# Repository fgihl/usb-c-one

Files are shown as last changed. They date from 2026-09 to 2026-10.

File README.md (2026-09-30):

# HIL USB-C Control

A bench device that sits between a Raspberry Pi and a USB-C device under test (DUT). Host software gets controlled access to the DUT's USB 2.0 data, USB-C CC attachment and 5 V VBUS, so it can emulate unplugging and reconnecting the DUT without touching its cable.

It is intended for controlled hardware-in-the-loop (HIL) lab rigs. It is not a general-purpose USB-C charger, dock or power-distribution product.

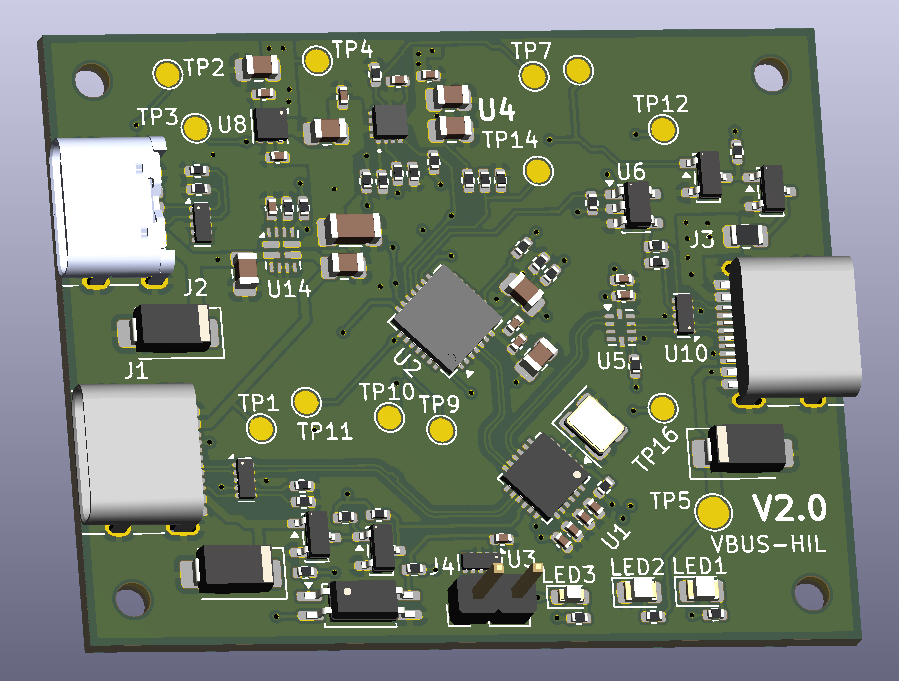
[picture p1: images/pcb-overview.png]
HIL USB-C Control PCB, V2.0 (3D render)


## Features

- USB 2.0 high-speed hub with a fixed on-board control interface. The Pi always sees the controller, whether or not a DUT is connected.
- Software-controlled J3 (DUT) state: data, CC/Rp and 5 V VBUS are switched independently.
- Priority power mux: external 5 V on J2 is preferred; J1 (the Pi) is the fallback and is reverse-blocked when J2 is valid.
- J3 VBUS is protected by an eFuse (about 3.6 A typical, below 4.0 A worst case) with over-voltage protection, fault reporting and active discharge.
- Fixed 3 A Rp advertisement on J3. No USB PD, BC1.2, VCONN, SuperSpeed or alternate modes.
- One opto-buffered external control line (J4) and test points for the key rails and signals.
- Controlled via `libgpiod` on the standard Linux `cp210x` gpiochip.

## Connectors

| Ref | Role |
|---|---|
| J1 | USB-C upstream to the Raspberry Pi: USB 2.0 data, and fallback VBUS |
| J2 | USB-C 5 V power input (power only, no data). Preferred over J1 |
| J3 | USB-C downstream to the DUT: switched data, CC and VBUS |
| J4 | External opto-buffered control line |

## Architecture

```mermaid
flowchart LR
  J1[J1 USB-C to Pi] -->|D+/D-| H[CH334F USB 2.0 hub]
  J1 -->|VBUS_UP| MUX[TPS2121 priority mux]
  J2[J2 5 V input] -->|VBUS_PWR| MUX
  MUX --> VSYS((VSYS))
  VSYS --> LDO[TLV76733 3.3 V LDO]
  LDO --> H
  H -->|port 1, fixed| C[CP2102N GPIO control]
  H -->|port 2| SW[TS3USB221A data switch]
  SW --> J3[J3 USB-C to DUT]
  LDO --> RP[Rp buffer] --> J3
  VSYS --> EF[TPS259470L eFuse] -->|VBUS_HIL| J3
  C --> EF
  C --> SW
  C --> RP
```

| Function | Part |
|---|---|
| USB 2.0 hub | CH334F |
| Control IC | CP2102N-A02 (7 GPIO) |
| Power mux | TPS2121 |
| J3 eFuse | TPS259470L |
| Data switch | TS3USB221A |
| 3.3 V LDO | TLV76733 |
| Rp buffer | SN74LVC1G125 |
| ESD | TPD4E05U06 |

Board: 4 layers, 50 x 40 mm, top-side SMT, designed for JLCPCB assembly.

## Operating cases

| Case | Power source | Use |
|---|---|---|
| A. Pi-powered | J1 only | Low-current DUTs only. Enumeration, data path and low-power control. |
| B. External 5 V | J2, with the Pi supplying data on J1 | Normal mode for high-current tests. The source must supply the DUT load plus about 0.1 A board consumption (at least 3.5 A for a 3 A DUT). |
| C. Split-cable | External 5 V on J1 VBUS, Pi supplies data and GND | Qualified fixtures only. The Pi-side VBUS must be isolated from the external supply. |

J1 and J2 accept regulated 5 V only. Sustained 12 V or 20 V input is outside the product contract.

## Software contract

Software owns the state machine. The hardware does not detect DUT attach and does not enforce source capability.

- **Disconnect:** data off, wait 20 ms, CC off, wait 20 ms, VBUS off, then wait for the discharge confirmation.
- **Connect:** CC on, VBUS on, confirm VBUS present and no fault, wait 40 ms, data on.

Before a high-current test, confirm that J2 is powering the board. Turn J3 VBUS off before planned J2 removal. The CP2102N GPIO map, configuration image and a control-service example are in [architecture/architecture_final.md](architecture/architecture_final.md) section 6.

## Repository layout

| Path | Contents |
|---|---|
| [product_description.md](product_description.md) | Product requirements, operating cases, accepted limitations, acceptance checks |
| [architecture/architecture_final.md](architecture/architecture_final.md) | Schematic-level architecture, power budget, GPIO map, BOM, risks, prototype tests |
| [architecture/schematic_overview.md](architecture/schematic_overview.md) | Schematic overview |
| [architecture/pcb_floor_plan.md](architecture/pcb_floor_plan.md) | PCB floor plan and layout constraints |
| [llm-kicad/](llm-kicad/) | KiCad 10 project (hierarchical schematic, PCB, custom symbols) |
| [llm-kicad/schematic_review_report.md](llm-kicad/schematic_review_report.md) | Schematic review report and finding log |
| [tools/](tools/) | Audit and helper scripts |

The schematic sheets are `01_power_cc`, `02_usb_hub_control`, `03_dut_interface` and `04_test_validation`. Open `llm-kicad/llm-kicad.kicad_pro` in KiCad 10.

## Tools

`tools/audit_schematic.py` checks symbol pin numbers against placed footprint pad numbers, schematic versus PCB footprint sync, `Value` text versus the JLCPCB catalogue part, and `Datasheet` coverage. It exits non-zero if the pin/pad or footprint-sync checks fail.

```sh
python3 tools/audit_schematic.py
```

## Known limitations

- Fixed 3 A Rp: the advertisement can exceed the active source's real capacity.
- No hardware DUT-attach detection: an unplugged DUT can leave J3 VBUS live until software disables it.
- A single priority mux is the only isolation between J1 and J2. It is not an independent-source isolator, and a split cable that joins an external supply to the Pi is not protected against.
- No per-input current limit or input over-voltage disconnect.

The full list and the release acceptance checks are in [product_description.md](product_description.md) sections 7 to 9.

## Status

Hardware revision V2.0. Before release, see the open items in the schematic review report and the mandatory prototype tests in [architecture/architecture_final.md](architecture/architecture_final.md) section 10. The CP2102N must be programmed with the configuration image before use.

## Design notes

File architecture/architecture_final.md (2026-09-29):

# HIL USB-C Control - Schematic-Level Architecture (v1)

Status: Draft for review round 1. This is a complete, standalone architecture derived from `product_description.md`; prior designs are archived in `architecture/V1/`.

## 0. Scope and decisions

| Area | Decision |
|---|---|
| USB topology | USB 2.0 High-Speed hub: one permanent control port and one switchable DUT port |
| Control IC | CP2102N-A02-GQFN28, exposed to Linux as a `cp210x` gpiochip |
| Input power | U14 TPS2121RUXR (C485916) J2-preferred dual-input priority mux with reverse-current blocking; J1 is the fallback |
| HIL power | One TPS259470L eFuse on J3 VBUS: 3.89 A current limit, OVP, fault output, controlled ramp and discharge |
| HIL CC | Software-enabled fixed 3 A Rp from 3.3 V: 4.79 kOhm per CC pin |
| Safety policy | Software sequences CC, VBUS and data. There is no hardware DUT-attach detector or source-capability detector. |
| PCB | Four layers, target 60 x 40 mm, no enclosure, top-side SMT with through-hole connector-shell pegs |
| Excluded | USB 3.x, USB PD, BC1.2, SBU, VCONN, DisplayPort and barrel jack |

**Qualified-input boundary:** J1 and J2 accept regulated 5 V only. They are not specified to survive or block a sustained 12 V or 20 V input. A USB-C PD source remains at vSafe5V because the board has no PD communication, but a PD trigger, a non-compliant source, or a 12 V supply is outside the product contract. Input TVS devices handle ESD and short hot-plug transients, not a sustained wrong-voltage supply.

## 1. Requirements traceability

| Requirement / scenario | How v1 satisfies it |
|---|---|
| Pi host, DUT device | J1 is the USB-C upstream connection to the Pi USB-A host port. J3 is a downstream USB-C DFP. |
| USB 2.0 HS only | CH334F hub, TS3USB221A HS switch, 90 Ohm differential routing and 0.5 pF ESD arrays. |
| Control survives DUT disconnect | CP2102N is fixed on hub port 1; only hub port 2 to J3 is switched. |
| Emulated unplug | U5 opens D+/D-, U6 removes Rp, U4 opens/discharges VBUS; software timing is mandatory. |
| Pi-powered low-current test | U14 selects J1 when J2 is absent. Software only permits a known low-current DUT. |
| External 3 A test | U14 selects J2 whenever valid. Fixture requires 5 V, at least 3.5 A, including board load. |
| Split-cable fixture | J1 accepts isolated external VBUS while Pi provides D+/D-/GND. A cable that ties external VBUS to the Pi is prohibited. |
| Never back-feed Pi | U14 reverse-blocks both inputs; J1 carries no HIL load when J2 is present. |
| HIL overload / short | U4 current limit, fast-trip, thermal latch-off and `HIL_FLT_N` report to software. |
| Deterministic default | CP2102N reset latches and pull resistors keep data open, Rp off, U4 EN low and discharge on. |
| Input fault scope | Only qualified 5 V inputs supported; connector TVS covers ESD/transients, not sustained 12/20 V. |

## 2. Topology and control-IC evaluation

| Option | Evaluation | Decision |
|---|---|---|
| USB 2.0 hub with separate control and DUT ports | Control stays enumerated while J3 is removed; true downstream data isolation is possible. | **Selected** |
| USB mux/data switch only | The CP2102N and DUT cannot coexist on one Pi port. | Rejected |
| Hub port power control only | Does not remove CC or guarantee D+/D- isolation. | Rejected |
| MCU plus hub | Enables richer policy and telemetry but adds firmware, update and debug responsibility. | Rejected for v1 |

| Candidate | GPIO and Linux support | Cost / availability posture | Result |
|---|---|---|---|
| Original CP2102 | No general GPIO | Inadequate | Rejected |
| **CP2102N-A02** | Seven GPIO lines through upstream `cp210x` gpiochip; `libgpiod` control | JLC Extended, archived C964632 | **Selected** |
| CH340 / CH9102 | Serial control only; no suitable standard gpiochip path | Low cost but insufficient GPIO | Rejected |
| FT231X / FT232H | GPIO through `ftdi_sio` / MPSSE | Higher cost; valid fallback | Alternative |
| RP2040 / CH32V / STM32 | Full GPIO and logic via CDC serial | Needs maintained firmware | Rejected |

## 3. Block diagram

```mermaid
flowchart LR
  J1[J1 USB-C upstream to Pi] -->|D+/D-| E1[U9 ESD] --> H[U1 CH334F USB 2 HS hub]
  J1 -->|VBUS_UP| MUX[U14 priority mux\nJ2 preferred]
  J2[J2 USB-C 5 V input] -->|VBUS_PWR| MUX
  MUX --> VSYS((VSYS))
  VSYS --> LDO[U8 3.3 V LDO]
  LDO --> H
  H -->|port 1, fixed| C[U2 CP2102N GPIO control]
  H -->|port 2| SW[U5 TS3USB221A]
  SW --> E3[U10 ESD] --> J3[J3 USB-C DUT]
  LDO --> RP[U6 3 A Rp buffer]
  RP --> J3
  VSYS --> EF[U4 HIL eFuse\n3.89 A / OVP]
  EF -->|VBUS_HIL| J3
  EF --> DIS[Q2/Q3 + 470 Ohm discharge]
  C -->|VBUS_EN / DATA_EN_N / CC_EN_N| EF
  C --> SW
  C --> RP
  E2[U11 ESD] --- J2
  TVS[VBUS TVS] --- J1
  TVS --- J2
  TVS --- J3
```

## 4. Power tree and budget

| Rail | Source / path | Design current | Function |
|---|---|---:|---|
| VBUS_UP | J1 | Pi-port-limited | Low-current fallback source |
| VBUS_PWR | J2 | Qualified 5 V / >=3.5 A | Preferred high-current source |
| VSYS | U14 priority mux | 4.2 A | Board and U4 input |
| +3V3 | U8 TLV76733DRVR | 150 mA | Hub, CP2102N, U5/U6, LEDs |
| VBUS_HIL | U4 TPS259470L | 3.89 A nominal | DUT power |

| Consumer | Rail | Typical | Maximum / allowance |
|---|---:|---:|---:|
| CH334F | +3V3 | 42 mA | 85 mA |
| CP2102N | +3V3 | 9.5 mA | 14 mA |
| U5/U6 and logic | +3V3 | 1 mA | 3 mA |
| LEDs | mixed | 5 mA | 7 mA |
| Regulators / mux Iq | VSYS | 2 mA | 5 mA |
| Board total | VSYS | about 60 mA | 115 mA |

A full 3 A DUT requires at least 3.115 A before connector/cable headroom. The specified J2 fixture source is 5 V and at least 3.5 A. A nominal 3 A charger is not a full-3-A DUT source.

## 5. Schematic implementation

### 5.1 Connectors, power mux and 3.3 V rail

- **J1/J3:** TYPE-C-31-M-12, 16-pin USB 2.0 receptacle with four through-hole shell pegs, LCSC C165948 (archived-verified; recheck stock before order). Join A6/B6 as D+ and A7/B7 as D-. SBU1/SBU2 are explicitly NC with no routed stub and no ESD device because no alternate mode is supported; this is an accepted bench-only ESD limitation.
- **J2:** TYPE-C-31-M-17, six-pin power-only USB-C receptacle, LCSC C283540 (archived-verified; recheck stock). It has VBUS, GND and CC only; no D+/D- path exists to invoke proprietary charging protocols.
- **U14:** TPS2121RUXR (Texas Instruments), LCSC C485916, VQFN-HR-12 2 x 2.5 mm, Extended, $1.044 and 37,201 stock in the Konnect JLC cache. Connect J1 to IN1 (pin 7) and J2 to IN2 (pin 2). Strap PR1 (pin 6) to GND and CP2 (pin 3) to J2 VBUS; CP2 above its 1.06 V reference and PR1 below it explicitly select IN2 whenever J2 is valid. With J2 absent or invalid, IN1 supplies the output. Tie OV1/OV2 (pins 5/4) to GND because inputs are qualified 5 V; connect ST (pin 9) to a 10 kOhm pull-up to +3V3 for source-status observation. Note there is no spare control line for it: all seven CP2102N GPIO are allocated (§6.1) and the QFN28 package has no GPIO.7, so ST is observable only by probing the R33 pad. Set ILIM (pin 10) and SS (pin 11) per the TI equations. The 56 mOhm integrated path and reverse-current blocking prevent J1 from sharing the J2 HIL load. Do not substitute a plain ideal-diode OR circuit.
- U14 is the only isolation element between J1 and J2. Its specified reverse blocking is verified by prototype test, but component failure is not guaranteed open-circuit. This attended, qualified-fixture board is not an independent-source isolator. Label J1/J2 accordingly and test J2 back-voltage with J1 active and vice versa.
- **U8:** TLV76733DRVR, LCSC C2848334 (archived-verified; recheck stock). IN=VSYS, EN=IN, OUT=+3V3, FB/SNS=OUT. C16 1 uF at IN; C17 10 uF/25 V and C18 100 nF at OUT.
- Add 100 kOhm / 100 kOhm dividers from VBUS_UP to GPIO.5 and from VBUS_PWR to GPIO.3. Each provides 2.5 V at a valid 5 V input. They are informational and do not control U14.

### 5.2 HIL VBUS and discharge

- **U4:** TPS259470LRPWR, LCSC C3662793 (archived-verified; recheck stock). IN=VSYS, OUT=VBUS_HIL. C9 10 uF + C10 100 nF at IN. For output transient performance fit C11/C12 as two 10 uF/0805/25 V X5R capacitors in parallel plus C13 100 nF; total nominal bulk is 20 uF. Validate <100 mV sag for a 0-to-3 A load step.
- EN/UVLO is `EN_HIL`: CP2102N GPIO.6 (pin 20, configured push-pull) -> R27 1 kOhm -> EN; R28 10 kOhm EN-to-GND. This yields a deterministic disabled state before GPIO configuration. R28 doubles as the 10 kOhm pull-down the CP2102N datasheet requires, because all pins float high during a device reset.
- ILM: R31=931 Ohm, 0402, 0.1%, LCSC C852955. The TPS259470L data sheet specifies 3.96/4.452/4.84 A min/typ/max at RILM=750 Ohm. Scaling that specified band by $750/(931 \times 1.001)$ and $750/(931 \times 0.999)$ gives 3.19-3.90 A; nominal is 3.59 A. This retains a 3 A DUT margin while bounding maximum current below 4.0 A. Validate the trip response and thermal behavior on prototype, but no further current-limit tolerance derivation is pending.
- OVLO: R29 49.9 kOhm (VSYS to OVLO) and R30 12 kOhm (OVLO to GND), yielding 6.19 V rising / 5.67 V falling. SMAJ6.5A has 6.5 V standoff, not a 6.5 V clamp; it does not suppress a 6.19 V OVLO trip. DVDT C14=1 nF. ITIMER open. FLT has R34 10 kOhm pull-up to +3V3 and reaches GPIO.0. U4 is the **latch-off (-L)** variant, so a thermal or ILM-short fault stays latched until explicitly cleared — the recovery contract is in §6.5. There is deliberately **no supply-side UVLO divider** on EN/UVLO (accepted risk, §10).
- Discharge: Q2 and Q3 are BSS138P,215 (C75547, SOT-23, Extended; 463,528 stock in the Konnect cache). R36 470 Ohm/0805 is from VBUS_HIL to Q3 drain; Q3 source is GND. Q3 gate has R37 100 kOhm pull-up to +3V3. When EN_HIL is high, Q2 conducts and pulls Q3 gate low, turning Q3 off so discharge is disabled. When EN_HIL is low, Q2 releases the gate and R37 turns Q3 on, enabling discharge. Q3 on resistance is negligible compared with 470 Ohm; the nominal 20 uF output discharges from 5 V to 0.8 V in 17 ms. `hil_off()` must report a discharge fault if its 150 ms confirmation timeout expires.
- `VBUS_HIL_SNS`: R38 10 kOhm from VBUS_HIL, R39 18 kOhm to GND, and R40 1 kOhm series to GPIO.1 (pin 18). At 5 V, GPIO sees 3.21 V.

### 5.3 USB hub, control and switched data

- **U1:** CH334F, LCSC C5187527 (archived-verified; recheck stock). Operate in 3.3 V self-powered mode: V5 and VDD33 to +3V3, each with 1 uF + 100 nF. Strap PSELF for the confirmed self-powered polarity. Y1 is X322512MSB4SI 12 MHz, LCSC C9002; external 22 pF load capacitors are DNP because CH334F provides internal loading.
- Hold U1 RESET#/CDP low while J1 VBUS is absent using Q6/Q7, both BSS138P,215/C75547. Q6 source=GND, drain=U1 RESET#, gate=`HUB_RESET_CTL`; R45=100 kOhm pulls RESET# to +3V3. Q7 source=GND, gate=VBUS_UP, drain=`HUB_RESET_CTL`; R46=100 kOhm pulls `HUB_RESET_CTL` to +3V3. With VBUS_UP absent, Q7 is off, Q6 gate is high, and Q6 asserts reset; with VBUS_UP present, Q7 pulls Q6 gate low and R45 releases reset. Never actively drive RESET# high. Confirm PSELF and reset behavior on prototype.
- **U2:** CP2102N-A02-GQFN28R, LCSC C964632 (archived-verified; recheck stock). U2 D+/D- connect to fixed U1 port 1. VDD gets 1 uF + 100 nF; VREGIN gets 1 uF. VBUS sense pin uses R43=22 kOhm from VSYS and R44=47 kOhm to GND.
- **U5:** TS3USB221ARSER, LCSC C128396 (archived-verified; recheck stock). Hub port 2 connects to common D+/D-; J3 connects to 1D+/1D-. Select=GND; 2D+/2D-=NC; OE#=`HIL_DATA_EN_N`; VCC=+3V3 with 100 nF.

### 5.4 CC, Rp, inputs and controls

- J1/J2 each have Rd: R1-R4, 5.1 kOhm from each CC pin to GND. This establishes a Type-C sink and makes a compliant J2 source apply vSafe5V.
- **U6:** SN74LVC1G125DBVR, LCSC C23654 (archived-verified; recheck stock). VCC=+3V3 with 100 nF; A=+3V3; OE#=`HIL_CC_EN_N`; Y=`VRP_3A`. It must offer power-off output isolation.
- From `VRP_3A` to J3 CC1 fit R5=4.7 kOhm; to J3 CC2 fit R6=4.7 kOhm (LCSC C25900, 0402, Basic). A single 4.7 kOhm from a buffered 3.3 V is the USB Type-C Table 4-24 3.3 V-column value for a 3 A advertisement. There is no R7/R8 placement option: the earlier 33 kOhm || 5.6 kOhm split was never built. Specify 1% parts and record the tolerance in the BOM (the specification's 3.3 V Rp leg is 4.7 kOhm +/-5%). Do not fit auxiliary 1 Mohm CC pull-ups: U6 output isolation leaves the line genuinely open when disabled.
- There is no PD controller, BC1.2 detector, VCONN or dynamic Rp. J3 advertises 3 A even in Pi fallback mode; software must prevent inappropriate loads.

## 6. Control interface and Linux contract

### 6.1 GPIO assignment (as built, and routing-verified)

All seven CP2102N GPIO pins on the QFN28 package are **bidirectional** — Rev 1.5
pin table: "Digital Input/Output. General Purpose I/O" for GPIO.0-GPIO.6 — and
every one supports both output modes, §4.3.3: *"Each pin has two options for the
output mode: push-pull and open-drain."* **There is therefore no input/output
constraint on which signal goes on which pin.** Only the per-pin *mode* in the
configuration image has to follow the signal, not the pin number.

The assignment below is what the schematic and board implement. It was also
tested as a routing question: scored against the placed board, it gives **zero
crossings** in the U2 fan-out (the minimum achievable) and a total first-hop
length within 1% (0.64 mm of 52 mm) of the best of all 5040 permutations. The
previous revision of this table was wrong on six of seven pins, and its
arrangement measured 2.75 mm longer **with two crossings** — so the table was
corrected to the hardware, not the hardware to the table.

| GPIO | Pin | Net | Mode | I/O | Active state | Default |
|---|---:|---|---|---|---|---|
| GPIO.0 | 19 | `HIL_FLT_N` | digital input | in | low = U4 fault | pull-up |
| GPIO.1 | 18 | `VBUS_HIL_SNS` | digital input | in | high = HIL VBUS present | divider |
| GPIO.2 | 17 | `HIL_CC_EN_N` | output, open-drain | out | low enables U6 Rp | released / high |
| GPIO.3 | 16 | `U14_ST` | digital input | in | **low = `VBUS_PWR` selected** | R33 10 kOhm pull-up |
| GPIO.4 | 22 | `HIL_DATA_EN_N` | output, open-drain | out | low enables U5 | released / high |
| GPIO.5 | 21 | `EXT_IO0` | output, open-drain, high drive | out | **low = opto LED on** | released / high |
| GPIO.6 | 20 | `HIL_VBUS_EN` | output, **push-pull** | out | high enables U4 | low |

Three points that the mode column depends on:

- `HIL_VBUS_EN` **must be push-pull.** It drives `EN_HIL` through R27 = 1 kOhm
  with R28 = 10 kOhm to GND, so it has to actively source current to exceed the
  TPS259470L's 1.20 V UVLO threshold. As an open-drain output it could not drive
  high and U4 would never enable.
- `HIL_DATA_EN_N` and `HIL_CC_EN_N` are open-drain and rely on R48 = 100 kOhm
  (U5 OE#) and R49 = 100 kOhm (U6 OE#) respectively, so their released state is
  high = disabled. Push-pull would also work; open-drain is used so the reset
  default is already the safe state.
- GPIO.5 **must be open-drain with latch = 1**, so it is inert at reset and through USB
  suspend. The opto LED is wired anode-to-`+3.3V` through R76 = 330 Ohm, cathode to the pin,
  so the pin sinks about 5.6 mA to turn the line on. That is why **high drive** is required:
  low drive sinks only 6.5 mA, which is right at the LED current; high drive sinks 13.5 mA.
  Push-pull would work electrically but its reset state is indistinguishable from asserted if
  the latch is ever set to 0.
- All **two** remaining sense pins (`HIL_FLT_N`, `VBUS_HIL_SNS`) are plain inputs into
  3.3 V-tolerant networks. GPIO.0-GPIO.3 have alternate functions (TXT / RXT / RS485 /
  WAKEUP on QFN28) - all unused and to be left disabled. GPIO.4-GPIO.6 have none.

`VBUS_HIL_SNS` is in §5.2, and `HIL_FLT_N` comes from U4's FLT pin.

**Changed 2026-09-29 - both VBUS sense dividers were removed.** `VBUS_PWR_SNS`
(R70/R71/R72) and `VBUS_UP_SNS` (R73/R74/R75) are deleted from the schematic, and their
test points TP13/TP15 with them. GPIO.5 is needed as an output for the one external
control line that fits, and GPIO.3 is the only other pin whose sense function could be
spent, so neither source can be read directly any more. §6.6.4 is therefore moot: the
sub-`V_IH` divider defect it describes no longer exists in the design, because the
dividers do not exist.

**`U14_ST` replaces them.** U14 is a TPS2121, and its `ST` pin is an open-drain status
output - TPS2121 datasheet, Recommended Operating Conditions: `V_ST` 0-5.5 V and
**`R_ST` "Status Pin Pull Up Resistance" = 6-20 kOhm, an *external* pull-up** (it sits
next to `R_ILM` 18-100 kOhm, which is also external). R33 = 10 kOhm to `+3.3V` is inside
that range, and because the part has no internal pull-up the high level is exactly 3.3 V -
comfortably above the CP2102N's `V_IH` = 2.7 V, and never above 3.3 V.

Datasheet behaviour: *"ST is pulled high when the output is Hi-Z or IN1. It is pulled low
when IN2 is powering the output."* On this board U14 pin 7 (`IN1`) is `VBUS_UP` and pin 2
(`IN2`) is `VBUS_PWR`, so:

| `U14_ST` (GPIO.3) | Meaning |
|---|---|
| high (1) | `VBUS_UP` (upstream USB-C) is powering VSYS, **or** the output is Hi-Z |
| low (0) | `VBUS_PWR` (auxiliary supply) is powering VSYS |

The Hi-Z case is unobservable in practice - both inputs invalid means the fixture is
unpowered. **The polarity is inverted relative to the old `VBUS_PWR_SNS`**, which read
high = present; firmware must flip the bit. The accepted loss is that only the *selected*
source is visible, so "both inputs present at once" can no longer be asserted - that was
the condition that would have verified U14's priority switchover.

### 6.2 Control truth table

| VBUS_EN | CC_EN_N | DATA_EN_N | J3 state |
|---:|---:|---:|---|
| 0 | 1 | 1 | Disconnected: VBUS discharged, Rp absent, D+/D- open |
| 0 | 0 | 1 | Rp present, VBUS/data off |
| 1 | 0 | 1 | VBUS and Rp present; data open |
| 1 | 0 | 0 | Connected: VBUS, Rp and data present |

### 6.3 Configuration image (`cp2102n_config.hex`)

Generate the image from the table in 6.1 — and ultimately from the **netlist**,
never from this document's prose, because a prose-to-netlist drift on exactly
this table is what the pin-permutation defect was. In Xpress Configurator:

| Setting | Value |
|---|---|
| GPIO.0, GPIO.1 | digital input |
| **GPIO.3** | **digital input** (reads U14 `ST`) |
| GPIO.2, GPIO.4 | digital output, **open-drain**, latch = 1 |
| **GPIO.5** | **digital output, open-drain, HIGH DRIVE, latch = 1** |
| GPIO.6 | digital output, **push-pull**, latch = 0 |
| GPIO.0-GPIO.3 alternate functions | disabled (TXT / RXT / RS485 / WAKEUP unused) |
| Suspend behaviour | leave at the default (pin latches hold during USB suspend) |
| Power | self-powered, max power 100 mA |
| UART | RXD (25) and TXD (26) are no-connect, as before |
| Modem pins | `RTS` (24) and `DTR` (28) are output-only test points (TP9/TP16) and need **no** host configuration; `CTS` (23), `DSR` (27), `DCD` (1) and `RI/CLK` (2) stay no-connect |
| Charging pins | CHREN, CHR0/CHR1 unconnected |
| Hardware flow control | **off** |

Release artifact: the generated `.hex`, its SHA-256, and the serial-number
policy. Never allow blank parts into PCBA; program and read back every unit
before final test.

### 6.4 Control service

Use one persistent service to own the GPIO lines. It must request them with the
default-off values already in the table, and must write those values again at
startup before enabling anything.

```python
# CP2102N on a cp210x gpiochip. Line index == GPIO number; confirm with
# `gpioinfo` that the chip labelled cp210x exposes seven lines.
LINE = {"hil_flt_n": 0,   # GPIO.0 pin 19  input
        "vbus_hil_sns": 1, # GPIO.1 pin 18  input
        "cc_en_n": 2,      # GPIO.2 pin 17  open-drain output
        "u14_st": 3,       # GPIO.3 pin 16  input; LOW = VBUS_PWR powering VSYS
        "data_en_n": 4,    # GPIO.4 pin 22  open-drain output
        "ext_io0": 5,      # GPIO.5 pin 21  open-drain output; LOW = opto LED on
        "vbus_en": 6}      # GPIO.6 pin 20  push-pull output

def hil_off():
    """Disconnected state. Returns only once VBUS has actually collapsed."""
    data_en_n.set(1); sleep(0.020)
    cc_en_n.set(1);   sleep(0.020)
    vbus_en.set(0)
    if not wait_until(lambda: not vbus_hil_sns.get(), timeout=0.150):
        raise RuntimeError("VBUS discharge timeout")

def hil_on(high_current=False):
    # high_current means the DUT is to run from the auxiliary supply, so that supply
    # must be the one actually powering VSYS. U14_ST is now the only way to know:
    # it reads LOW exactly when U14 has selected IN2 = VBUS_PWR.
    if high_current and u14_st.get():
        raise RuntimeError("aux supply not selected - is J2 connected and valid?")
    cc_en_n.set(0)
    sleep(0.010)          # let Rp settle before presenting VBUS
    vbus_en.set(1)
    wait_until(lambda: vbus_hil_sns.get() and hil_flt_n.get(), timeout=1.0)
    sleep(0.040)          # inrush/ramp settles before closing the data path
    data_en_n.set(0)

def ext_out(asserted):
    """Drive the single external opto-isolated line.

    Path: GPIO.5 -> U15 LED -> U15 collector -> EXT_OUT0 -> U3 clamp -> J4 pin 2.
    Active low, and the polarity is preserved end to end: asserted sinks the LED,
    which turns the phototransistor on and pulls the far-side node to GND.
    Released (and unpowered) leaves it pulled up by R79, so the DUT-side default
    is the inert high.
    """
    ext_io0.set(0 if asserted else 1)

def source_selected():
    """'vbus_pwr' | 'vbus_up'. Note ST is inverted versus the old sense divider."""
    return "vbus_pwr" if not u14_st.get() else "vbus_up"
```

A fault-recovery path is also required — see §6.5.

### 6.5 Fault latch-off and recovery (U4)

U4 is the **TPS259470L**, the latch-off variant. Per the datasheet (Table 7-3) some
faults latch internally and stay latched until explicitly cleared, while others do
not:

| Event | Response | Latched? | FLT pin |
|---|---|---|---|
| Overtemperature (TJ >= TSD) | Shutdown | **Yes** | low |
| ILM pin shorted to GND | Shutdown | **Yes** | low, after tITIMER |
| Undervoltage (UVP or UVLO) | Shutdown | No | high |
| Input overvoltage | Shutdown | No | high |
| Persistent overcurrent | Current limit | No | low, after tITIMER |
| ILM pin open (steady state) | Shutdown | No | low, after tITIMER |
| Output short to GND | Current limit | No | high |
| Reverse current | Reverse-current blocking | No | low |

Because **ITIMER is open**, a sustained overcurrent is *limited* rather than latched:
the part sits in current limit and only latches if it then overheats. So on this
board the latched faults to design for are **overtemperature** and **ILM shorted to
GND**.

**How a latched fault is cleared** (Table 7-2 and §7.3.9). The die must first fall
below `TSD - TSD_HYS`, and then **either**:

1. VIN cycled to 0 V and back above `VUVP(R)` (~2.53 V), or
2. **the EN/UVLO pin taken below `VSD(F)`** — min 0.45 V, max 0.74 V.

**The trap, in the datasheet's own words:** *"During a latched fault, pulling the
EN/UVLO just below the UVLO threshold has no impact on the device."* The UVLO falling
threshold is `VUVLO(F)` = 1.09 V typ, which is **above** `VSD(F)` (0.74 V max). Taking
EN low to a level that merely crosses the UVLO threshold leaves the part latched, and
so does releasing it to high impedance: at high impedance `EN_HIL` sits at the
R27/R28 divider level, which is above `VSD(F)`. The low must be a **hard low, below
0.74 V with margin** — target below 0.45 V so it holds across the full tolerance band.

This design can meet that: `HIL_VBUS_EN` (GPIO.6, push-pull) drives `EN_HIL` through
R27 = 1 kOhm with R28 = 10 kOhm to GND, so driving the line low pulls `EN_HIL` to
about 0 V.

**Software contract:**

- `hil_off()` already drives `HIL_VBUS_EN` low, so it *is* the recovery primitive. Its
  low period must be explicit — hold low for at least 10 ms — rather than left to
  call ordering.
- Provide `hil_fault_clear()` = the EN-low hold followed by re-enable. After a thermal
  or ILM-short fault, FLT stays low until this is done, so treat "FLT low and
  `VBUS_HIL_SNS` low" as **latched — needs a clear**.
- Do **not** auto-retry in a tight loop while the cause persists. A latched thermal
  fault means the DUT is overloading the fixture or the board is too hot. Report it
  and require an explicit command, or retry with a bounded back-off that is recorded.
- Clearing the latch also **releases FLT**. FLT returning high is not evidence that the
  load is healthy — re-check `VBUS_HIL_SNS` and the actual current before resuming.
- While latched, `VBUS_HIL` is off, so `VBUS_HIL_SNS` reads low. Software must not
  report that as "DUT unplugged" when it is the consequence of its own fault latch.
- The Pi cannot power-cycle `VSYS` (option 1 above) without dropping the whole fixture,
  so the EN toggle is the only practical recovery path — which is exactly why the
  hard-low requirement matters. Confirm it on the prototype (mandatory prototype
  test 5).

### 6.6 Planned change: additional host-controllable I/O (partly built)

**Status 2026-09-29: BUILT, and reduced from three channels to one.** Only one external
line fits the board, so sheet 04 carries a single optocoupler stage (`U15`) driven by GPIO.5,
with its clamp, filter capacitor and 2-pin connector. `DTR` and `RTS` were **not** given opto
stages - they are broken out as test points `TP9`/`TP16` instead. §6.1 is now the as-built
record for the seven GPIOs. What remains is the config image and the PCB work.

**Interface decision (revised from the first draft):** the output stage uses an
**optocoupler**, not a directly-driven open-drain line. For "might be 3.3 V, might be 5 V" the
opto is the better answer: the far-side logic level is set by the far side's own pull-up, so
one board works at any level, and the barrier means a mis-wire on the connector provably
cannot reach the CP2102N. It supersedes the DNP `BSS138` branch — do not fit both.

Motivation: the fixture needs general-purpose lines the host can drive to control external
equipment. The first use case is enabling and cutting power to the DUT from an **external
bench supply**, independently of the on-board U4 eFuse path.

#### 6.6.1 Where the extra lines come from

CP2102N §4.3.1 caps the part at "up to 7 GPIO", so there is no eighth GPIO, and the rail
senses cannot be merged onto one pin because the GPIOs are **digital only — the part has no
ADC**, so a resistor ladder cannot distinguish levels. The extra lines therefore come from
two places: one freed GPIO, and the part's unused modem-control interface.

| Line | Source | Direction | Notes |
|---|---|---|---|
| `EXT_IO0` | GPIO.5 (pin 21), freed | out | was `VBUS_UP_SNS` |
| `EXT_IO1` | `RTS` (pin 24) | out | test point `TP9` only - no opto fitted |
| `EXT_IO2` | `DTR` (pin 28) | out | test point `TP16` only - no opto fitted |
| `U14_ST` | GPIO.3 (pin 16) | in | takes over from `VBUS_PWR_SNS` |

#### 6.6.2 `U14_ST` to GPIO.3, freeing GPIO.5

TPS2121 `ST` is an open-drain status output: **high = IN1 (`VBUS_UP`) is feeding VSYS;**
**low = IN2 (`VBUS_PWR`) is feeding VSYS.** In this design U14 pin 7 = IN1 = `VBUS_UP` and
pin 2 = IN2 = `VBUS_PWR`, and J2 has hard priority through the CP2/PR1 comparison. ST is
also high when the output is Hi-Z, which is unobservable here: with no selected source the
board is unpowered and the host cannot read the pin. One pin therefore carries both
input-presence facts, so it replaces `VBUS_PWR_SNS` **and** `VBUS_UP_SNS`:

- GPIO.3 takes `U14_ST`. The net must become a **global label** — this project has no
  hierarchical labels, and U2 lives on a different sheet from U14.
- GPIO.5 becomes **free**: delete R73/R74/R75 and the `VBUS_UP_SNS` label. TP15 sits on that
  net and goes with it — re-point TP15 at `VBUS_UP` if raw-rail probing is still wanted.
- Delete R70/R71/R72 and the `VBUS_PWR_SNS` label; TP13 goes with it.

**No new components are needed for this.** `R33` is already a 10 kOhm pull-up from `U14_ST`
to `+3.3V`, so ST is already a clean 3.3 V logic signal — **do not add a divider.**

**Polarity inverts.** The old `VBUS_PWR_SNS` read high = present; `U14_ST` reads **low =
`VBUS_PWR` selected**. The firmware bit must be updated with it.

**Accepted loss:** ST reports only the *selected* source, so "both inputs present at once"
is no longer observable. That is precisely what would be checked to verify U14's priority
switchover, so if that test matters, keep `VBUS_PWR_SNS` and put ST on GPIO.5 instead —
which then frees nothing.

#### 6.6.3 `DTR` and `RTS` as extra outputs

These are **modem-control functions, not GPIO** (CP2102N §4.3.11), enabled by the VCP
driver when the host configures the COM port. From Linux via pySerial: `p.dtr = True`,
`p.rts = ...` to drive; `p.cd`, `p.dsr`, `p.ri`, `p.cts` to read. This is a **second device
node**, not the cp210x gpiochip.

Two cautions straight from the datasheet:

- **"DTR ... may toggle when opening a COM port on some operating systems."** For a
  power-control line this is the main practical hazard; choose a polarity where the toggle is
  inert, or filter it (100 kOhm / 100 nF = about 10 ms into a Schmitt input).
- Do not enable RTS/CTS **hardware handshaking** (§4.3.7) if RTS is repurposed.

`DCD` (1), `DSR` (27), `RI` (2) and `CTS` (23) stay no-connect for now. They are the
documented extension path for host-readable inputs.

#### 6.6.4 Defect found while deriving this: two sense dividers are below `V_IH`

CP2102N Table 3.7 gives **`V_IH` = VIO - 0.6 = 2.7 V** (VIO = VDD = 3.3 V; the QFN28 has no
separate VIO pin). Against that:

| Sense | Divider | Level at VBUS = 5.0 V | vs `V_IH` = 2.7 V |
|---|---|---|---|
| `VBUS_PWR_SNS` | R70 100 kOhm / R71 100 kOhm | **2.50 V** | below spec |
| `VBUS_UP_SNS` | R73 100 kOhm / R74 100 kOhm | **2.50 V** | below spec (net being removed anyway) |
| `VBUS_HIL_SNS` | R38 10 kOhm / R39 18 kOhm | 3.21 V | fine |

At the USB minimum of 4.75 V the first two fall to 2.375 V. They work in practice — real
thresholds sit nearer VDD/2 — but they are out of specification and should not be relied on
in a fixture.

**Fix:** change **R71 from 100 kOhm to 150 kOhm** (3.00 V at 5.0 V, 2.85 V at 4.75 V, both
comfortably above 2.7 V). R74 disappears with `VBUS_UP_SNS`. The replacement sense needs no
change: R33 already pulls `U14_ST` to `+3.3V`.

#### 6.6.5 External interface: protection rules

The CP2102N is the only host link on the board — if it is damaged the whole fixture becomes
unreachable — so it must be the best-protected part on the board. Threats on an exposed
line: ESD through the connector, a mis-wire putting an external rail onto a signal, a short
to GND, reverse polarity, ground offset between fixture and external equipment, inductive
kickback, and hot-plug transients.

Rules adopted:

1. **Never take the chip pin to a connector unbuffered.** Series resistor (100 Ohm) plus a
   clamp **at the connector**, not at the chip.
2. **Reuse the existing ESD array.** `TPD4E05U06` (already fitted as U9/U10/U11 — 4 channels,
   5.5 V working voltage, +/-12 kV contact) covers four lines with one part. It clamps
   *transients*; it is not sustained-overvoltage protection.
3. **Open the interface where the part allows it.** Table 3.7 specifies input leakage for
   `VIO < VIN < VIO + 2.0 V`, and §4.3.3 permits an open-drain output to be "pulled to the
   higher, external voltage through an external pull-up resistor". So reaching 5 V needs no
   level shifter. Keep any external pull-up at or below `VIO + 2 V` (5.3 V).
4. **Above about 5 V, or driving real current, needs a barrier.** `BSS138` is already in the
   BOM (Q2/Q3/Q6/Q7); at 60 V Vds / +/-20 V Vgs it survives a 12/24 V mis-wire. Per-line
   barrier footprints are placed but **DNP**, so a line can be converted without a respin.
5. **Define the safe state in all four conditions**: unpowered, during reset, with the port
   closed, and during USB suspend. The GPIO default is open-drain with a weak pull-up and
   latch = 1, i.e. released/high; §4.3.1 makes the suspend and post-reset states
   configurable, so set them explicitly in the config image.
6. **Keep "loss of host = safe".** If the PC crashes or the cable is pulled, DTR normally
   releases — arrange the external logic so the DUT then loses power.
7. **Connector hygiene**: keyed or unambiguously silkscreened, a GND pin adjacent to every
   signal, a DNP series-resistor footprint per line, a test point per line, and the clamp
   return kept short to the In1/B.Cu ground plane. If the lines leave the enclosure on a
   cable, add 100 pF - 1 nF per line to ground and consider a common-mode choke.

#### 6.6.6 Circuit adopted per output line

> **Superseded (2026-09-29).** This variant was not adopted. The operator rejected taking a
> CP2102N pin to a connector at all, and chose an optocoupler buffer instead — see §6.6.9.
> The text below is kept as the record of the alternatives that were considered, including
> the DNP `BSS138` branch, which is no longer needed because the opto already provides the
> barrier.

```
CP2102N pin --[100R]--+-- connector pin --+-- [10k] to GND
                      |                   +-- [100pF] to GND
                      |                   +-- TPD4E05U06 channel
                      +-- [DNP: BSS138 gate + 100k to GND, drain pulled to external rail]
```

Output mode: **push-pull, default low**. `EXT_IO0`/`EXT_IO1`/`EXT_IO2` therefore read
**low = inert** at the connector, which is also the state with the board unpowered (the
10 kOhm pull-down). The DNP `BSS138` branch converts a line to an inverting open-drain drive
whose high level is set by the far side, for a >5 V or active-low load.

New connector **J4**, 1x6 keyed header: `GND, EXT_IO0, EXT_IO1, EXT_IO2, EXT_IN0, EXT_IN1`.
The two `EXT_IN` positions are reserved and unpopulated for now; populating them costs one
divider each and shares the existing ESD array.

Assumptions taken when this was written (the operator was not available to confirm them):
the far side is a **high-impedance logic input**; the external domain is **3.3 V, with up to
24 V mis-wire tolerance via the DNP barrier**; **common ground** is assumed, so no galvanic
isolation is fitted — if the external equipment turns out to be floating or on a separate
earth, an opto or digital isolator stage is required instead, and the DNP footprint is where
it goes.

#### 6.6.7 What the change touches

- `01_power_cc.kicad_sch`: `U14_ST` promoted to a global label; R70/R71/R72 and R73/R74/R75
  removed; `VBUS_UP_SNS` and `VBUS_PWR_SNS` labels removed.
- `02_usb_hub_control.kicad_sch`: U2 pins 21, 28 and 24 un-no-connected; new `EXT_IO*`
  labels; new J4 and its protection network.
- `architecture_final.md`: this section, plus §6.1, §6.2 (source-selection readback) and §9 BOM.
- `cp2102n_config.hex`: regenerate — GPIO.5 push-pull output with its reset and suspend latch
  set to the inert state; GPIO.3 unchanged as a digital input; confirm no handshaking.
- Linux control service: `EXT_IO0` still on the cp210x gpiochip; `EXT_IO1`/`EXT_IO2` and any
  inputs through pySerial on the VCP device node.

#### 6.6.8 Implementation status and the built circuit

**Built on sheet 04 (`04_test_validation.kicad_sch`), right-hand side - ONE channel:**

| Ref | Part | Value | Footprint | LCSC |
|---|---|---|---|---|
| U15 | `Isolator:PC817` symbol, LTV-217 part | `LTV-217` | `Package_SO:SOP-4_4.4x2.6mm_P1.27mm` | C115450 |
| R76 | LED series resistor | `330R 0402` | `R_0402_1005Metric` | C25104 |
| R79 | output pull-up | `10k 0402` | `R_0402_1005Metric` | C25744 |
| U3 | 4-channel ESD clamp array | `TPD4E05U06DQA` | `Package_SON:USON-10_2.5x1.0mm_P0.5mm` | C138714 |
| C2 | connector filter capacitor | `100pF` | `Capacitor_SMD:C_0402_1005Metric` | C1546 |
| J4 | far-side connector | 1x2, 2.54 mm | `PinHeader_1x02_P2.54mm_Vertical` | C49257 |
| TP9, TP16 | `DTR` / `RTS` breakout | `EXT_I01`, `EXT_02` | - | C49257 |

Wiring: `+3.3V` - R76(330R) - U15 pin 1 (anode); U15 pin 2 (cathode) - global label
`EXT_IO0`; U15 pin 3 (emitter) - GND; U15 pin 4 (collector) - global label `EXT_OUT0`,
R79(10k) to `+3.3V`, C2 to GND, and U3 channel D1+ (plus its straight-through NC pin 10,
which TI sanctions) on to J4 pin 2.

`U15` is driven by **GPIO.5 (pin 21)** - `EXT_IO0` reaches `U2.21`. The two unused clamp
channels and the other three `TPD4E05U06` pins are left floating.

**Note:** only one of the array's four channels is used, so the 10-pin USON `U3` is now
larger than the job needs. The same device family has a single-channel part,
**`TPD1E05U06`** (2-pin X1SON 0.6x1 mm or DFN1006-2; C2937017 $0.033, C436349 $0.06,
C3001953 $0.024) - worth swapping if board space gets tight. TI's layout footnote still
applies: keep it at the connector.

- **Drive the LED by sinking, never sourcing.** The CP2102N is asymmetric: 7 mA source but
  **13.5 mA sink** in high-drive mode (3.1.7). +3.3 V through 330 Ohm gives about **5.6 mA**
  of LED current, right at the LTV-217's 5 mA CTR test condition. Configure the driving GPIO
  as **open-drain, high drive** — released/high is then LED off, i.e. the reset and suspend
  defaults are already the inert state.
- **Connector polarity is active-low**: the phototransistor conducts and pulls the far-side
  node low when the LED is on. An active-high far side needs one extra inversion stage.
- **CTR is 130-260 % at 5 mA**, so the 10 kOhm pull-up is comfortable even at half typical
  CTR and after CTR degradation with age and temperature.
- **Cost of the choice:** about 5.6 mA from the 3.3 V rail whenever the line is asserted,
  microsecond edges, and one extra 4-pin part. (Three channels were once planned; only one
  is fitted, so the rail cost is one third of the figure quoted in earlier revisions.)
- The `isolated_pin_label` warnings are **gone**. They cleared once `EXT_IO0` reached
  `U2.21` on sheet 02.

**Trap hit and fixed while placing these:** `add_power_symbol` auto-numbers `#PWR` "to the
lowest number free **on the sheet**", which collided with sheet 02 (it produced `#PWR010`..
`#PWR015`, all already used there). KiCad requires `#PWR` references to be unique across the
whole project; the duplicates made `kicad-cli sch export netlist` print *"schematic has
annotation errors"*. They were renumbered to `#PWR0200`..`#PWR0205`. Always check `#PWR`
uniqueness **project-wide**, not per sheet, after adding power symbols.

**Protection network built (2026-09-29).** Between U15's collector and J4 there is a 10 kOhm
pull-up (R79), a 100 pF capacitor (C2) and one `TPD4E05U06` channel (`U3` D1+, whose
straight-through NC pin 10 TI sanctions carrying the signal on to the connector). Verified
from the netlist:

```
EXT_OUT0 -> C2.1, J4.2, R79.1, U15.4, U3.1, U3.10
EXT_IO0  -> U15.2, U2.21          the LED is now driven by GPIO.5
U14_ST   -> R33.1, U14.9, U2.16   ST on GPIO.3, 10 kOhm pull-up to +3.3V
```

See §6.6.9 for why each of those parts is there.

**Sheet 02 is done.** Pins now read: `U14_ST` on 16 (GPIO.3), `EXT_IO0` on 21 (GPIO.5),
`EXT_IO1` on 24 (`~{RTS}`) and `EXT_IO2` on 28 (`~{DTR}`) - the last two to test points only.
`~{CTS}` (23), `~{DSR}` (27), `~{DCD}` (1) and `~{RI}` (2) keep their no-connect flags, and no
pin carries both a label and a no-connect flag.

**Remaining:**

- **`cp2102n_config.hex`** - the only schematic-adjacent task left. GPIO.5 must become an
  output (open-drain, high drive, latch 1); GPIO.3 stays a digital input; hardware flow
  control off. Generate it from the netlist, never from §6.1's prose.
- **PCB:** `U3` and `C2` must sit **at J4**, not at the opto - TI's pin table says "Place as
  close to the connector as possible" for every clamp channel.
- **PCB:** U15/R76/R79 also want to be near J4 rather than where the schematic draws them.
- **Cosmetic, but it prints on the silkscreen:** J4's Value reads `Conn_01x02_Socket` on a
  header footprint, and the two new test points read `EXT_I01` (should be `EXT_IO1`) and
  `EXT_02` (should be `EXT_IO2`).
- **`J4` has no LCSC code** since the symbol was swapped from 1x3 to 1x2 (the old `C49257`
  was a 1x3 part). A 1x2 2.54 mm replacement: `C492410` (`PZ254R-11-02P`).

**Schematic layout note.** The capacitors were first placed in a vertical chain at x = 238.76
and ran straight through the title block (which occupies x 177-285, y 166-198 on A4
landscape). They were moved into the clear band above it as a horizontal row at y = 146-159.
Check the title block's extent before placing anything in the lower-right of an A4 sheet.

#### 6.6.9 Interface decision (adopted 2026-09-29): opto-buffered open collector

**The CP2102N is never taken to a connector.** Each of the three host-control lines is
buffered by an optocoupler, so the chip pin only ever sees its own LED loop inside a package.
This supersedes both variants in §6.6.6 — the bus-buffered open drain, and the DNP `BSS138`
branch, which is now redundant because the opto already provides the barrier.

**No galvanic isolation is claimed or provided.** U15 pin 3 (emitter) returns to *board* GND
and the 10 kOhm pull-up goes to *board* +3.3 V, so both sides of the barrier reference the
same ground and the isolation rating does nothing. This was a deliberate
acceptance, not an oversight: the DUT is already tied to the fixture ground through USB-C
(J3), so there is no separate far-side ground to isolate to, and real isolation is not
achievable in this topology. The opto earns its place as a **signal** barrier — a transient
on the collector cannot reach the gate-side node at all — not as an isolation barrier.

**Why an ESD clamp is still needed.** Without one, energy at J4 flows into the first thing on
the net: the 10 kOhm 0402 pull-up (rated about 50 V, so it simply breaks down) and then the
+3.3 V rail, which feeds U1 and U2. The opto bounds but does not remove that path, so `U3`
puts one `TPD4E05U06` channel on the line and shunts the pulse to GND. The part is
0.5 pF / 5.5 V working / IEC 61000-4-2 rated and is already in the BOM as U9/U10/U11. It
clamps **transients only**; its 5.5 V standoff means it is the wrong part if a line is ever
left parked at 12 V.

**Why 100 pF.** With the 10 kOhm pull-up it sets a deliberate edge-rate limit:

$$\tau = RC = 10\,\text{k}\Omega \times 100\,\text{pF} = 1\,\mu\text{s} \qquad
f_c = \tfrac{1}{2\pi RC} \approx 159\,\text{kHz}$$

so cable-induced RF, contact bounce on plugging in and ESD remnants are all integrated away
instead of becoming a logic edge; the slower edge also removes the high-frequency harmonics a
cable would otherwise radiate (CISPR/EN 55032), and it gives the clamp diodes an AC path to
GND so they have time to turn on. It is small on purpose: 100 nF against 10 kOhm would give
1 ms, far too slow for a control line.

**Layout rule.** TI's pin table footnote on every clamp channel reads *"Place as close to the
connector as possible"*. `U3` and `C2` must therefore be placed at **J4** in the PCB layout,
with the clamp's ground return kept short to the In1/B.Cu plane — not next to the opto, where
they are drawn on the schematic.

**Accepted limitations.** The 10 kOhm on-board pull-up fixes the idle high level at 3.3 V; a
DUT-side pull-up to its own (e.g. 5 V) rail overrides it and the node settles about 0.5 V
below that rail, which is still a valid high — but a 5 V input with *no* pull-up of its own
would only see 3.3 V, below 5 V CMOS `V_IH` (about 3.5 V). `EXT_IO1`/`EXT_IO2` were reduced to
test points (`TP9`/`TP16`) and carry no opto stage, so if they are driven at all it is as modem
outputs through pySerial rather than from the cp210x gpiochip. `EXT_IO0` is the only line that
uses a real GPIO, and it is now connected to `U2.21` (see §6.6.8).

## 7. Sequences and fail-safe states

```mermaid
sequenceDiagram
  participant Pi
  participant CP as CP2102N
  participant U5 as Data switch
  participant U6 as Rp buffer
  participant U4 as HIL eFuse
  Pi->>CP: data off
  CP->>U5: OE# high, D+/D- open
  Note over Pi: wait 20 ms
  Pi->>CP: CC off
  CP->>U6: OE# high, Rp open
  Note over Pi: wait 20 ms
  Pi->>CP: VBUS off
  CP->>U4: EN low, output off
  U4->>U4: 470 Ohm discharge, below 0.8 V within 36 ms
```

```mermaid
sequenceDiagram
  participant Pi
  participant CP as CP2102N
  participant U6 as Rp buffer
  participant U4 as HIL eFuse
  participant U5 as Data switch
  Pi->>CP: CC on, VBUS on
  CP->>U6: Rp enabled
  CP->>U4: EN high, controlled VBUS ramp
  Pi->>CP: check VBUS_HIL_SNS and FLT_N
  Note over Pi: wait 40 ms
  Pi->>CP: data on
  CP->>U5: OE# low, DUT enumerates
```

```mermaid
sequenceDiagram
  participant DUT
  participant U4 as HIL eFuse
  participant CP as CP2102N
  participant Pi
  DUT->>U4: overload / short
  U4->>U4: current limit then fast-trip or thermal latch
  U4->>CP: FLT_N low
  CP->>Pi: fault event
  Pi->>CP: data off, CC off, VBUS off
```

| Condition | J3 state | Mechanism |
|---|---|---|
| Power-up, U2 reset, failed enumeration | Disconnected | GPIO latches and pull resistors |
| Pi reboot | Disconnected until service starts | Same defaults |
| U4 thermal fault | VBUS off, FLT low | U4 latch-off; service disables all outputs |
| DUT physically unplugged | Can remain powered until service turns it off | Accepted software-only limitation |
| J2 added while J1 present | J2 supplies VSYS, J1 reverse-blocked | U14 priority mux |

## 8. ESD, indicators, test points and layout

| Location | Protection / implementation |
|---|---|
| J1 D+/D-/CC1/CC2 | U9 TPD4E05U06DQAR, C138714, 0.5 pF ESD array |
| J3 D+/D-/CC1/CC2 | U10 TPD4E05U06DQAR, C138714 |
| J2 CC1/CC2 | U11 TPD4E05U06DQAR, C138714; unused channels grounded |
| J1/J2 VBUS | SMAJ20A, C115250. Transient/ESD support only; sustained incorrect voltage is unsupported. |
| J3 VBUS | SMAJ6.5A, C123817, coordinated with U4 OVLO |
| LEDs | Green VSYS, yellow VBUS_HIL, red +3V3-to-FLT_N; 1 kOhm each |
| Test points | VBUS_UP, VBUS_PWR, VSYS, +3V3, VBUS_HIL, GND, U4 ILM/EN/FLT, three GPIO enables, three GPIO senses, D+/D- in-route vias |

- Shells go directly to GND with short, wide copper and at least four stitching vias per connector. Reserve DNP 1 Mohm || 4.7 nF chassis-link footprints only if a metal enclosure is added.
- Use four layers: L1 signals/components, L2 solid GND, L3 VSYS/VBUS_HIL pours, L4 low-speed signals. Route USB at 90 Ohm differential impedance using JLC's chosen four-layer stack-up, <0.15 mm skew, no stubs and <=2 vias per pair.
- Floor plan: J1 left edge; U9 then U1/Y1 left-center; J2 top edge beside U14 and input TVS; U4/bulk capacitors top-right; U5/U10 between U1 and J3 on right edge; U2 bottom-center; U8 near the 3.3 V loads. Keep ESD within 3 mm of connector pins and switching/high-current loops away from Y1/U1.
- Barrel jack is dropped: a safe third source needs reverse blocking and a qualified OVP path, exceeding the three-part target. Use a regulated USB-C supply at J2.
- Thermal target: U14 dissipation at 3.12 A is approximately $3.12^2 \times 56\ m\Omega = 0.55\ W$ nominal. U4 is approximately $3^2 \times 17\ m\Omega = 0.15\ W$ using its typical on resistance. Place U14 and U4 over copper pours with at least four thermal vias. U8 worst-case dissipation is $(5.25-3.3) \times 0.115 = 0.22\ W$. At 3 A DUT load from J2, measure 10-minute temperature rise; no device may thermal-shutdown and U14/U4 package surface rise should remain below 40 C above ambient.
- Before PCB layout, select the current JLC four-layer impedance stack-up in its impedance calculator and record its 90 Ohm differential width/spacing in the PCB constraints. This architecture does not freeze a stack-up code that JLC could change.

## 9. BOM summary and procurement status

| Group | Approx. qty | Cost at qty 10 | Status |
|---|---:|---:|---|
| ICs, connectors, TVS, FETs, LEDs, crystal | 24 | $8-11 | Includes Q2/Q3/Q6/Q7; all core entries were rechecked in the Konnect cache below |
| Resistors | 36 | about $0.35 | 0402 except R36 470 Ohm 0805 |
| Capacitors | 23 | about $0.90 | Includes 20 uF output bulk and VSYS bulk |
| Total | 83 BOM placements (+14 test points, +4 mounting holes) | $10-14 plus assembly fees | 35 unique LCSC codes |

The passive table below is generated **from the design**, grouped by part code, and was reconciled against the schematic on 2026-09-28. The earlier revision listed two parts that do not exist (R7/R8) and carried pre-fix values for R28, R34, R5/R6, C23/C25 and C5 — see the review report's H4/H5/M2/M11 findings.

| Passive / refdes | Value and package | LCSC | Qty |
|---|---|---|---:|
| R1-R4 | 5.1 kOhm, 0402, 1% (J1/J2 Rd) | C25905 | 4 |
| R5/R6 | 4.7 kOhm, 0402, 1% (J3 Rp) | C25900 | 2 |
| R27/R40/R47/R50/R51/R52/R72/R75 | 1 kOhm, 0402, 1% | C11702 | 8 |
| R28/R33/R34/R35/R38 | 10 kOhm, 0402, 1% | C25744 | 5 |
| R37/R45/R46/R48/R49/R70/R71/R73/R74 | 100 kOhm, 0402, 1% | C25741 | 9 |
| R29 | 49.9 kOhm, 0402, 1% | C25897 | 1 |
| R30 | 12 kOhm, 0402, 1% | C25752 | 1 |
| R31 | 931 Ohm, 0402, 0.1% | C852955 | 1 |
| R32 | 24 kOhm, 0402, 1% | C25769 | 1 |
| R36 | 470 Ohm, 0805 | C17710 | 1 |
| R39 | 18 kOhm, 0402, 1% | C25762 | 1 |
| R43 | 22 kOhm, 0402, 1% | C25768 | 1 |
| R44 | 47 kOhm, 0402, 1% | C25792 | 1 |
| C1/C3/C23/C25 | 4.7 uF, 0805, 25 V X5R | C1779 | 4 |
| C9/C11/C12/C17 | 10 uF, 0805, 25 V X5R | C15850 | 4 |
| C5 | 47 uF, 1206, 10 V X5R on a 1210 land — **the value text says 100 uF; see report M11** | C96123 | 1 |
| C6/C10/C13/C18/C20/C22/C24/C26/C27/C28 | 100 nF, 0402, 16 V X7R | C1525 | 10 |
| C14 | 1 nF, 0402 | C1523 | 1 |
| C16/C19/C21 | 1 uF, 0402, 25 V X5R | C52923 | 3 |

Active FETs: Q2/Q3/Q6/Q7 are BSS138P,215, LCSC C75547, SOT-23, Extended; 463,528 stock in the Konnect cache. Konnect cache verification at this revision: U14 TPS2121RUXR/C485916 (37,201 stock); U4 TPS259470LRPWR/C3662793 (2,842); U2 CP2102N/C964632 (42,417); U1 CH334F/C5187527 (4,767); U5 TS3USB221A/C128396 (92,432); U6 SN74LVC1G125/C23654 (102,950); U8 TLV76733/C2848334 (20,010); ESD C138714 (175,385); J1/J3 C165948 (93,517); J2 C283540 (9,051). No listed selected core part is below 1,000 stock or marked EOL in that cache.

## 10. Assumptions, risks and prototype tests

### Assumptions and accepted shortcuts

- Board target is 60 x 40 mm with no enclosure; this is an engineering default awaiting confirmation.
- J2 is a qualified 5 V, >=3.5 A fixture source. Sustained 12/20 V at J1/J2 is unsupported.
- Pi-only operation is software-limited to known low-current DUTs even though J3 advertises 3 A.
- A split cable isolates Pi VBUS from the external 5 V leg.
- HIL off after reset/fault is acceptable.
- There is no automatic physical-detach shutdown: a physically removed DUT can leave J3 VBUS live until the service disables it.
- **No supply-side UVLO divider on U4 EN/UVLO (M4) — accepted.** `EN_HIL` is driven only by the 3.3 V GPIO, so whenever EN is high the eFuse passes whatever VSYS is. VSYS between U4's own `VUVP(R)` (~2.53 V) and the USB-C 4.75 V minimum therefore reaches J3 as "VBUS" while below spec. The window is narrow in practice: below roughly 3.6 V the 3.3 V rail collapses, the hub and CP2102N brown out and the USB path drops anyway. Backstops: software checks `VBUS_UP_SNS`/J2 presence before enabling, and a brown-out must be reported as a failed test rather than a valid run.
- **U5's unused `2D+/2D-` pins left open (M8) — accepted.** TI recommends 50 Ohm to GND on unused switch pins (`U5.3`/`U5.4`) to avoid reflections. None are fitted because no signal can reach that port: `SEL` is strapped to GND, so the 2D path is never selected, and the pins are no-connect. Revisit only if a future revision makes that port selectable.

### Open questions

1. Confirm CH334F PSELF polarity and reset/pull-up behavior on prototype.
2. Program CP2102N with Silicon Labs Xpress Configurator before release, using the per-pin modes in §6.3: GPIO.6 push-pull (latch 0), GPIO.2 and GPIO.4 open-drain (latch 1), GPIO.0/1/3/5 digital inputs, GPIO.0-3 alternate functions disabled, self-powered at 100 mA. The released production package must contain `cp2102n_config.hex`, generated from the §6.1 assignment — and ultimately from the netlist, not from this document — plus its SHA-256 and serial-number policy; do not allow blank parts into PCBA. Program and read back each unit before final test.
3. Confirm on a fresh Raspberry Pi OS image that `/dev/gpiochipN [cp210x]` exposes all seven lines, that the **line index matches the GPIO number** (line 6 = GPIO.6 = `HIL_VBUS_EN`, the enable that must be push-pull), and that the chosen GPIO levels work at 3.3 V.
4. Confirm acceptance of Pi-powered low-current operation with fixed 3 A Rp.
5. Confirm the board envelope and whether an enclosure changes the shell grounding approach.

### Mandatory prototype tests

1. With J1 and J2 present at 3 A DUT load, verify J1 current is negligible and J2 is the sole HIL source.
2. Remove J2 at 0.5 A, 1.1 A and 3 A; verify the service disables U4 and characterize reset behavior.
3. Verify the complete data/CC/VBUS disconnect and reconnect sequences, including VBUS <0.8 V in 60 ms.
4. Verify USB HS eye/throughput through U5 and disconnect/re-enumeration behavior.
5. Verify U4 current-limit, fast-trip, thermal latch, FLT report and recovery.
6. Verify Pi-powered known-low-current DUTs do not trip the Pi port.
7. Verify qualified J2 high-current operation, voltage drop and thermal rise at the full DUT load.
8. Verify U14 reverse blocking: drive one input at 5 V, leave the other unpowered or short it to GND through a current meter, and require <=10 uA reverse current. Repeat for both input directions.
9. Verify IEC 61000-4-2 bench robustness: +/-4 kV contact to accessible connector pins and +/-8 kV air to shells, both with DUT traffic active; no latch-up, no HIL enable without a software command, and USB re-enumeration within 2 seconds.
10. At a 0-to-3 A load step, verify VBUS_HIL sag below 100 mV; also remove J2 while U4 is current-limiting and verify a defined fault/off state.
11. Mate J2 with at least five representative USB-C 5 V sources and verify CC attach, 5 V delivery, and retention. Qualify an alternate connector before production if any fail.
12. Perform ten HIL connect/disconnect cycles at ten-second intervals; no false eFuse trip, enumeration hang, or recovery latency above two seconds is allowed.

## 11. Review response log - round 1

| Finding | Decision | v2 response |
|---:|---|---|
| 1 U14 unverified | Accepted | Selected TPS2121RUXR, C485916, VQFN-HR-12; stock and price verified in Konnect cache. |
| 2 Q2/Q3 unspecified | Accepted | Named BSS138P,215/C75547 and corrected discharge truth description. |
| 3 incomplete passives | Accepted | Added named sense/Rp/Rd networks and passive procurement schedule. |
| 4 secondary reverse block | Rejected | A series Schottky wastes 5 V margin; U14 is the specified reverse-blocking boundary. Failure limitation, labels, and reverse-current test are explicit. |
| 5 CP2102N production risk | Accepted | Added programming image/configuration and fresh-Pi GPIO validation gate. |
| 6 mux failure mode | Accepted | Documented attended-fixture limitation and reverse-isolation test. |
| 7 contradictory discharge wording | Accepted | Rewritten with explicit transistor states. |
| 8 unnamed dividers | Accepted | Added R70-R75 definitions. |
| 9 weak CC pull-ups | Accepted | Removed; U6 power-off isolation is the off-state mechanism. |
| 10 thermal analysis | Accepted | Added power estimate, thermal layout and prototype target. |
| 11 stack-up unspecified | Accepted | Added pre-layout JLC impedance-calculator gate. |
| 12 ESD test | Accepted | Added IEC bench test. |
| 13 provisioning | Accepted | Added CP2102N configuration image/manufacturing requirement. |
| 14 split-cable detection | Accepted limitation | Software treats J1 fallback as low-current unless the fixture explicitly declares a qualified split supply; no inference from voltage sag. |
| 15 no detach detector | Accepted limitation | Controlled, attended-fixture scope; the service owns the off sequence. |
| 16 fault logging | Accepted | Service must log FLT and source-sense transitions and require operator acknowledgement before fault retry. |

## 12. Review response log - round 2

| Finding | Decision | v3 response |
|---:|---|---|
| C1 TVS/OVLO interaction | Resolved | Clarified SMAJ6.5A 6.5 V is standoff, not clamp voltage; U4 OVLO is 6.19 V rising and trips first. |
| C2 U4 ILM tolerance | Resolved pending vendor confirmation | Replaced parallel network with verified 866 Ohm/1% C227251, 3.85 A nominal and 3.81-3.89 A resistor-only range; datasheet/prototype current-limit validation is a release gate. |
| C3 U14 priority unspecified | Resolved | Added pin-level `J1->IN1`, `J2->IN2`, `PR1->GND`, `CP2->J2` XREF configuration and fallback behavior from TI TPS2121 data sheet. |
| C4 CP2102N image absent | Release artifact gate | Architecture now specifies exact configuration and mandatory generated/read-back `cp2102n_config.hex`; binary image is a manufacturing release artifact, not fabricated in this architecture-only phase. |
| M1 discharge timeout | Resolved | Added 150 ms confirmation timeout and error path. |
| M2 CC/VBUS race | Resolved | Added 10 ms CC-settle delay before VBUS enable. |
| M3 U14 single-point failure | Accepted limitation | Retained attended-qualified-fixture limitation; added labels, fault logging, and nominal reverse-current test. No Schottky is added because its drop erodes the 5 V margin. |
| M4 output transient | Resolved as prototype gate | Replaced 22 uF/1206 output capacitor with two 10 uF/0805 parts and added <100 mV 3 A step test. |
| M5 J2 compatibility | Resolved as prototype gate | Added five-source mating/attach qualification and alternate-connector trigger. |
| M6 GPIO levels | Release gate | Fresh-Pi OS gpiochip/level measurement remains mandatory before production release. |
| M7 thermal model | Resolved as prototype gate | Thermal layout and 10-minute full-load test remain required before production release. |
| M8 supply alternatives | Accepted procurement procedure | Cache stock is acceptable for prototype; production BOM release must add alternates or waive each single-source part. |

## 13. Review response log - round 3

| Finding | Decision | v4 response |
|---:|---|---|
| CRIT-1 output capacitor BOM mismatch | Resolved | C11/C12 are two 10 uF/0805 C15850 parts; nominal output bulk is 20 uF and the discharge calculation is 17 ms. |
| MAJ-1 missing Q6/Q7 | Resolved | Added complete BSS138P reset-control topology, R45/R46, four-FET active schedule, and exact LCSC mapping. |
| MIN-1 U4 thermal power | Resolved | Added 0.15 W nominal U4 dissipation estimate. |
| MIN-2 SBU handling | Resolved | Declared no-stub, no-ESD SBU handling as a bench-only accepted limitation. |

## 14. Review response log - round 4

| Finding | Decision | v5 response |
|---:|---|---|
| M-1 U4 current-limit final tolerance | Resolved | Replaced 866 Ohm with 909 Ohm C327324. The TPS259470L published 750 Ohm min/typ/max limits scale to 3.27-4.00 A including the 1% resistor; nominal is 3.67 A. Product brief aligned. |
| MIN-1 discharge timeline | Clarified | 17 ms is the 20 uF/470 Ohm nominal calculation; the 36/60/150 ms values are software/test margins. |
| MIN-2 CC/VBUS timing | Accepted refinement | 10 ms CC-settle delay remains an architecture-level implementation requirement. |
| MIN-3 CH334F prototype behavior | Release gate | PSELF/reset prototype verification remains mandatory but is fully specified for capture. |

## 15. Post-review correction

The fifth independent review found no Critical or Major defects. A subsequent arithmetic check showed that its acceptance of the prior 909 Ohm R31 maximum rounded $4.034$ A down to 4.0 A. To make the product brief's strict below-4.0-A statement true, R31 is changed to C852955 (931 Ohm, 0.1%). The exact data-sheet-scaled bounds are 3.1869 A minimum, 3.5865 A typical, and 3.9029 A maximum. This is a self-contained numerical correction; it does not alter topology, controls, CC behavior, layout, or any review disposition.

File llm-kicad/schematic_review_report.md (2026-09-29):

# USB-C HIL Control — Schematic Review Report (v8)

**Project:** `llm-kicad` (USB-C HIL Control, HIL USB-C bench fixture)
**Scope:** `llm-kicad.kicad_sch` + `01_power_cc`, `02_usb_hub_control`, `03_dut_interface`, `04_test_validation`
**Reviewed against:** `product_description.md`, `architecture/architecture_final.md`, `schematic_review.prompt.md`
**Date:** 2026-09-27 · **Method:** `kicad-schematic-review-skill` (structured extraction + datasheet contract) with 6 parallel subagent workstreams, then independent spot-checks against raw files, vendor datasheets and `kicad-cli` ERC.
**Verification stamp:** every finding below was re-checked against the extracted pin/net facts, the raw `.kicad_sch` values, and a vendor datasheet or the USB Type-C specification. Confidence and evidence are stated per finding.

**Revision history**

| Rev | Date | Change |
|---|---|---|
| v2 | 2026-09-27 | Initial structured review: 5 H, 10 M, 10 L; first fix pass (H1–H5). |
| **v3** | 2026-09-27 (later) | Adds **H6** (crystal pad mapping — a hub-killing defect found after v2). Records **M1** and **M2** as fixed, **M6** and **M7** as accepted (owner decision), **M5** as recommend-accept on analysis, and **M4/M8/M9** as still open. Corrects the net named in **M3** and the `ST` description in **M6**. Adds a new **PCB layout** section (fab blocker, design-rule decisions, current DRC state) and **M11** (C5 value/part mismatch). Refreshes every ERC/DRC figure. Supersedes v2. |
| **v4** | 2026-09-27 (final) | Re-checked from scratch against the saved files after the owner's edit pass. Adds **H7** — the CP2102N GPIO map in the architecture contradicts the schematic, and following it would leave U4 disabled and J3 unable to advertise (the top schematic item). Adds the automated **pin-number vs pad-number audit** (101 footprints, 0 mismatches). Rewrites **M3** (all ERC suppression removed; 4 errors / 2 warnings) and **M11** (C5 is now a value/part/land three-way mismatch). Corrects matrix rows 16 and 22, adds a "Verified at v4" section and a **Where to continue** list. Supersedes v3. |
| **v5** | 2026-09-28 | **H7 FIXED on the document side** after a measured routing study: all 5040 pin assignments were scored against the placed board, and the existing wiring turned out to be already crossing-free and within 1% of the shortest, so no pin swap was made and the architecture was corrected instead. Records the resulting `architecture_final.md` §6.1–§6.4 rewrite (table, configuration manifest, control-service example) and the removal of the bogus `GPIO.7` claim. Updates the verdict, matrix row 16 and the release gates. Supersedes v4. |
| **v6** | 2026-09-28 | **Nine of eleven medium findings closed.** M4 and M8 **accepted** by owner decision, M11 **fixed** (C5 reverted to `47uF 10V` / C96123 / 1206 — value, part and land now agree; the audit is clean), and M9 **documented** as `architecture_final.md` §6.5 — which also corrected this report's own advice: a latched fault clears only when EN/UVLO goes *below* `VSD(F)` (0.45–0.74 V), not merely below the UVLO threshold (1.09 V). Only M3 and M10 remain. Supersedes v5. |
| **v7** | 2026-09-28 | **M10 FIXED** — all 43 stray project-scope `instances` records removed. Verified byte-for-byte (replaying the deletion against the backups reproduces the live files exactly), ERC and audit unchanged, and the acceptance test passed: Konnect now resolves U2, U1, U5 and R34, the previously-refused symbols. **Only M3 remains open.** Supersedes v6. |
| **v8** | 2026-09-28 | **Corrects a false claim in v4–v7.** Those revisions said *"all ERC suppression has been removed… the result is finally trustworthy"*. That was wrong: I had been reading `schematic.erc` (an empty decoy) instead of the top-level **`erc`** key, and my report greps filtered out the `; warning (excluded)` markers and the ` ** Ignored checks:` block. **The 3 exclusions were present the whole time.** M3 rewritten with the true state; verdict corrected. Also records that two of M3's four flags were genuinely added and verified on 2026-09-28 (`PWR_FLAG #FLG01` on `VBUS_PWR`; no-connect flags on U1 pins 5/6), and adds a tested forecast of what un-suppressing would surface (notably `footprint_filter` on U1's stale `ki_fp_filters`). Supersedes v7. |

---

## Verdict

**ALL SEVEN HIGH FINDINGS CLEARED — TWO SMALL SCHEMATIC ITEMS AND ONE PCB FAB BLOCKER REMAIN.** H1–H5 (first pass), **H6** (crystal pad mapping — a hub-killing wiring defect) and **H7** (the CP2102N GPIO map, where the document contradicted the hardware and following it would have left U4 disabled and J3 unable to advertise) are all resolved. H7 was fixed on the **document** side, after a measurement showed the hardware wiring was already the routing optimum and that the document's own map would have been a regression.

The design is in good shape and measurably better than at v3: a full **pin-number vs pad-number audit across all 101 placed footprints found zero mismatches**, the architecture document now matches the netlist pin-for-pin (verified programmatically, 7/7), and the USB-C CC/Rd/Rp implementation is fully compliant and needed no change.

**⚠️ One claim in v4–v7 was wrong, and is corrected here: the ERC suppression was never removed.** Three objects are still excluded and four checks are still set to `ignore` — see **M3**. The "1 error / 2 warnings" quoted by earlier revisions were suppressed counts, not real ones.

**Remaining schematic work is one flag and one cleanup, both under M3:** (1) add a `PWR_FLAG` to **GND** — the last genuinely undriven net (the `VBUS_PWR` flag and the two U1 port-4 no-connect flags were added on 2026-09-28 and verified); (2) delete the three `erc_exclusions`, and enable **`footprint_filter`** — which currently hides a real leftover, U1's stale `ki_fp_filters`. Nothing else on the schematic is open except the L1–L10 naming/documentation tidies.

**Ten of eleven medium findings are closed:** M1, M2, M10 and M11 fixed, M9's recovery contract written into the architecture, and M4/M5/M6/M7/M8 accepted by owner decision with the risk recorded in `architecture_final.md` §10.

| Severity | Count | Status |
|---|---:|---|
| **H** | 7 | **All 7 fixed and verified** |
| **M** | 11 | M1, M2, M9, M10, M11 **fixed** · M4, M5, M6, M7, M8 **accepted** (owner decision) · **M3 open** |
| **L** | 11 | Open (L1–L11) — documentation/tidiness only |

**Release gates (in order):** (1) **M3** — add the `PWR_FLAG` on GND, delete the three `erc_exclusions`, and enable `footprint_filter` (fixing U1's `ki_fp_filters`) → a truthful ERC with nothing hidden; (2) generate `cp2102n_config.hex` from §6.1 with the per-pin modes in §6.3, built from the netlist — not from the prose that H7 caught; (3) confirm the §6.5 fault-recovery contract on the prototype (mandatory prototype test 5); (4) PCB — fix U4's footprint polygons (the only *fabrication* blocker), route the last ~30 nets, restore the netclass via size to `0.5/0.3`.

---

## Fix log — changes applied 2026-09-27

All changes were applied through Konnect's schematic tools (except where noted) and verified by re-parsing the saved files and re-running ERC.

| Ref | Change | Before → After | Sheet | Finding |
|---|---|---|---|---|
| U1 | Footprint | `QFN-24-1EP_3x4mm_P0.4mm_EP1.65x2.65mm_ThermalVias` → `QFN-24-1EP_4x4mm_P0.5mm_EP2.6x2.6mm_ThermalVias` | 02_usb_hub_control | H1 |
| R32 | Value + footprint + LCSC | `15.4k 1%` / `R_0603_1608Metric` / `C2933150` → `24k` / `R_0402_1005Metric` / `C25769` | 01_power_cc | H2 |
| D1 | Value + LCSC | `SMAJ20` / `C115250` → `SMAJ6.5A` / `C123817` | 04_test_validation | H3 |
| D2 | Value + LCSC | `SMAJ20` / `C115250` → `SMAJ6.5A` / `C123817` | 04_test_validation | H3 |
| R28 | Value + LCSC | `100k` / `C25741` → `10k` / `C25744` | 01_power_cc | H4 (applied in KiCad) |
| R33 | LCSC | `C11702` (1 kΩ) → `C25744` (10 kΩ) | 01_power_cc | H5 |
| R34 | LCSC | `C11702` (1 kΩ) → `C25744` (10 kΩ) | 01_power_cc | H5 (applied in KiCad) |
| R35 | LCSC | `C11702` (1 kΩ) → `C25744` (10 kΩ) | 02_usb_hub_control | H5 |

### Fix log — second pass (applied in KiCad by the design owner; verified here by re-export and re-parse)

| Ref | Change | Before → After | Sheet | Finding |
|---|---|---|---|---|
| Y1 | Symbol | `Device:Crystal` (2 pins) → `Device:Crystal_GND24` (4 pins) | 02_usb_hub_control | **H6** |
| Y1 | Value / LCSC | `12MHz X322512MSB4SI` → `Crystal 12MHz`; LCSC `C9002` | 02_usb_hub_control | **H6** |
| Y1 | Footprint | `Crystal_SMD_2520-4Pin_2.5x2.0mm` (tried) → back to `Crystal_SMD_3225-4Pin_3.2x2.5mm` | 02_usb_hub_control | **H6** |
| Y1 | Wiring | pad 2 (`XO`) → pad 3 (`Xtal Out`); pads 2 & 4 → `GND` (previously no-connect) | 02_usb_hub_control | **H6** |
| Y1 | Datasheet | *(empty)* → LCSC CDN PDF for C9002 | 02_usb_hub_control | M7 |
| J2 | Symbol | `USB_C_Receptacle_USB2.0_16P` → `Connector:USB_C_Receptacle_PowerOnly_6P` | 01_power_cc | **M1** |
| C23 | Value / LCSC / footprint | `1 µF` / `C52923` / `C_0402_1005Metric` → `4.7uF 25V` / `C1779` / `C_0805_2012Metric` | 02_usb_hub_control | **M2** |
| C25 | Value / LCSC / footprint | `1 µF` / `C52923` / `C_0402_1005Metric` → `4.7uF 25V` / `C1779` / `C_0805_2012Metric` | 02_usb_hub_control | **M2** |
| C28 | New part | added `100nF` / `C1525` / `C_0402_1005Metric` at U2 VREGIN (the pin previously had no 0.1 µF) | 02_usb_hub_control | **M2** |

### Fix log — third pass (applied in KiCad by the design owner; re-verified here from the saved files)

All four sheets and the project were re-saved at 22:01; this pass records what changed and what it did to the ERC result.

| Ref | Change | Before → After | Sheet | Finding |
|---|---|---|---|---|
| ERC config | `rule_severities` + `erc_exclusions` | four checks at `ignore` and two exclusions → **all removed**; every check back at default severity | project | **M3** |
| U1 | Downstream port usage | ports re-wired so **ports 1 and 2** are populated (`U1.11/12` → CP2102N, `U1.9/10` → U5); ports **3 and 4** are the unused ones | 02_usb_hub_control | **M3** |
| U1 | No-connect flags | port-3 pins (`U1.7/8`) now flagged; **port-4 pins (`U1.5/6`) not yet** | 02_usb_hub_control | **M3** |
| C5 | Value / footprint | `47uF 25V` / `C_1206_3216Metric` → `100uF 10V` / `C_1210_3225Metric` (PCB re-synced to the same 1210 land at 22:17; **LCSC left at `C96123`, which is a 47 µF part** — see M11) | 01_power_cc | **M5/M11** |

**Design-rule changes (project settings, not schematic)**

| Change | Value | Reason |
|---|---|---|
| Via geometry (all 65 placed vias) | `0.45/0.3` → **`0.5/0.3`** (ring 0.075 → **0.100 mm**) | Clears `annular_width` without relaxing any board rule; `min_via_annular_width` stays at 0.1 mm. See the PCB section. |
| `USB_90` netclass clearance | `0.5` → `0.15 mm` | 0.5 mm is geometrically impossible at U2's 0.5 mm pitch. |
| New custom rule `Keep copper pour clear of USB_90 pairs` | `clearance ≥ 0.4 mm` for Zone ↔ `USB_90` | Restores the original 0.5 mm intent for the pour only, without re-breaking the pads. |
| New custom rule `USB_90 intra-class clearance` | `clearance ≥ 0.15 mm` for `USB_90` ↔ `USB_90` | Allows the QFN-28 pad-to-pad spacing. |

**Verification after the fixes**

- Re-parsed all four sheets and the root: every affected part reads back exactly as intended, and no other footprint or value changed.
- Whole-board BOM integrity: every component value now maps to **exactly one** LCSC code, with **0 value/part mismatches** across the 36 parts that carry an LCSC code (the `10k` → C11702/C25744 split is gone).
- `kicad-cli sch erc` re-run after the first pass: **4 messages — 1 error (the pre-existing, excluded GND `power_pin_not_driven`), 3 warnings** — unchanged from the pre-fix run, so no regression and the files remain valid.
- **ERC, current state** (`kicad-cli 10.0.5 sch erc`): **4 messages — 3 errors, 1 warning**: two `pin_not_connected` (U1.11 `DM1−`, U1.12 `DP1+`), one `power_pin_not_driven` on **`VBUS_PWR`** (see M3 — the earlier report named the wrong net), and one `lib_symbol_mismatch` warning for **J1** only (J2's cleared when M1 was fixed). Target after the M3 actions: **0 errors**.
- Diff scope vs. the previous commit: `01_power_cc` 7 lines, `02_usb_hub_control` 2 lines, `04_test_validation` 4 lines — every changed line is accounted for by the table above.

**PCB re-sync — done (was outstanding at v2).** The layout has been re-synced from the schematic and is now heavily routed; all H-fix values and land patterns are present on the board, all 65 vias were re-sized, and the copper pours were re-filled. Current board state is in the **PCB layout** section.

**Process note — KiCad overwrites external edits.** A KiCad project save rewrites every sheet from its in-memory copy. On 2026-09-27 at 13:22:31 a KiCad save silently reverted four edits that had already been written to disk through Konnect while the sheets were open in KiCad (R33 LCSC, R35 LCSC, D1 and D2). Rule going forward: **close the schematic, or quit KiCad, before editing sheets through Konnect** — then reopen — or make the change inside KiCad.

---

## Must-fix findings

### H1 — U1 (CH334F) had the wrong footprint: 3×4 mm / 0.4 mm pitch assigned to a 4×4 mm / 0.5 mm part
**Status: ✅ FIXED 2026-09-27.** U1 now uses `Package_DFN_QFN:QFN-24-1EP_4x4mm_P0.5mm_EP2.6x2.6mm_ThermalVias`, verified against the WCH package drawing §5.5 `QFN24_4×4×0.75-0.5` (body 4.0 ± 0.1 mm, **exposed pad 2.6 ± 0.2 mm**, 0.5 mm pitch, 24 pads + pad 25 = EPAD, which matches the symbol's pin 25 → GND). Two loose ends: the symbol's `ki_fp_filters` still reads `…EP2.7x2.7mm*` (will flag if the footprint-filter ERC check is re-enabled — M3), and the schematic's embedded symbol copy still holds the stale 3×4 mm default, so an "update symbols from library" would revert it.
- **What:** `U1` footprint is `Package_DFN_QFN:QFN-24-1EP_3x4mm_P0.4mm_EP1.65x2.65mm_ThermalVias` (3×4 mm body, 0.4 mm pitch).
- **Why it's wrong:** the WCH CH334/335 datasheet package table specifies **`QFN24_4×4  4*4mm  0.5mm … CH334F`**. The LCSC catalog independently lists C5187527 as **`QFN-24(4x4)`**. A 3×4 mm / 0.4 mm land pattern cannot accept a 4×4 mm / 0.5 mm part — the board would be scrapped.
- **Fix:** assign `Package_DFN_QFN:QFN-24-1EP_4x4mm_P0.5mm_EP2.6x2.6mm_ThermalVias` (present in the installed KiCad library; re-check the EP variant against the WCH land-pattern drawing).
- **Evidence:** WCH CH334/335 V2.91 Table 1-2; JLCPCB cache C5187527 `Package = QFN-24(4x4)`; extraction `02_usb_hub_control` `U1.footprint`. **Confidence: high.**

### H2 — U14 (TPS2121) current-limit resistor R32 = 15.4 kΩ was outside the datasheet range and set ≈6.2 A
**Status: ✅ FIXED 2026-09-27.** `R32 = 24k` / LCSC `C25769` (`0402WGF2402TCE`, 0402, ±1%) → `I_LM = 65.2/24^0.861 ≈ 4.23 A`: above the eFuse's 3.89 A worst case, below the mux's 4.5 A rating, inside the datasheet's 18–100 kΩ R_ILM range.
- **What:** `R32 = 15.4k 1%` on net `U14_ILIM_PENDING` → `U14.10 (ILIM)`.
- **Why it's wrong:** the datasheet recommends **R_ILM = 18 kΩ … 100 kΩ** and publishes the relation `I_LM = 65.2 / R_ILM^0.861` (R in kΩ, I in A). That relation reproduces **all five** published table rows (18.7 kΩ→5.2 A, 22.1→4.5, 29.8→3.5, 44.2→2.5, 80→1.5) and the datasheet's own worked example (59 kΩ → 1.95 A). For **15.4 kΩ it gives ≈6.2 A** — above the device's **4.5 A max continuous input current** and above the **4.2 A VSYS design budget**.
- **Correction to the previous report:** the recorded "15.4 kΩ → 4.23 A" comes from a linear `I = 65.2/R` reading; it does not match the datasheet table.
- **Fix:** `R32 ≈ 24 kΩ` → ≈4.2 A (comfortably above the 3.89 A eFuse limit, below the 4.5 A device rating). Minimum acceptable is 18 kΩ (≈5.4 A). Add the ILIM pin to the lab check list.
- **Evidence:** TPS2121 datasheet §9.3.2 + ILIM table + §10.2.4.3 worked example; extraction `01_power_cc` net `U14_ILIM_PENDING`. **Confidence: high.**

### H3 — D1/D2 (SMAJ20) on J1/J2 VBUS could not protect the 5 V inputs at all
**Status: ✅ FIXED 2026-09-27.** D1 and D2 are now `SMAJ6.5A` / LCSC `C123817`, matching D3 — 6.5 V stand-off (safely above the 5.5 V VBUS maximum) with breakdown from ≈7.2 V. Remaining caveat, unchanged by the fix: this is a **sacrificial clamp** — it limits the excursion rather than guaranteeing the mux's ≈6 V limit. Guaranteed protection would require using the mux's OV1/OV2 pins (currently tied to GND), which changes fall-back behaviour and is not currently in the product contract.
- **What:** `D1 = SMAJ20` on `VBUS_UP` (J1) and `D2 = SMAJ20` on `VBUS_PWR` (J2).
- **Why it's wrong:** SMAJ20 is a **20 V stand-off** device (V_BR 22.2–24.5 V, clamp ≈32 V at 12.3 A). It does not conduct below ~22 V, while the TPS2121's IN1/IN2 inputs and the CP2 control pin are **≈6 V absolute maximum** (control-pin operating range 0–5.5 V). A USB-C hot-plug transient (cable ringing routinely reaches 8–10 V) therefore reaches the mux unclamped. The stated intent — "TVS devices handle ESD and short hot-plug transients" — is not achieved by this part.
- **Coupled risk:** `CP2 (pin 3)` is tied **directly** to J2 VBUS, leaving only 0.5 V of margin to the 6 V absolute maximum; the datasheet's comparator configurations use a divider on this pin.
- **What is correct:** `D3 = SMAJ6.5A` on `VBUS_HIL` is the right class of device for a 5 V rail and is correctly coordinated with U4's 6.19 V OVLO trip (the OVLO acts first; the TVS handles the faster/larger event).
- **Fix:** use a 5.0–6.5 V stand-off TVS on J1 and J2 VBUS (SMAJ5.0A / SMAJ6.0A / SMAJ6.5A) and verify the clamp stays below the mux's absolute maximum at the expected surge current. Consider a divider on CP2 for extra margin.
- **Evidence:** extraction values `D1/D2 = SMAJ20`, `D3 = SMAJ6.5A`; TPS2121 Section 6 + Table 7.1/7.3. **Confidence: high** (part selections verified; the clamp/stand-off relationship is standard TVS data).

### H4 — U4 enable default was indeterminate: R28 = 100 kΩ was too weak (VBUS could be live on J3 at power-up)
**Status: ✅ FIXED 2026-09-27.** `R28 = 10k` / LCSC `C25744` (applied inside KiCad — see M10 for why Konnect refused the symbol) → EN_HIL ≈0.3 V worst case with the CP2102N's 10–30 µA weak pull-up, comfortably below the TPS259470L's 1.183 V minimum rising threshold. The eFuse can no longer enable at power-up before software writes its defaults.
- **What:** `HIL_VBUS_EN` = `U2.22 (GPIO.4)` → `R27 = 1 kΩ` → `EN_HIL` → `U4.1 (EN/UVLO)`, with `R28 = 100 kΩ` to GND.
- **Why it's wrong:** the CP2102N's documented default is *"open-drain with a weak pull-up enabled and the port latch set to 1"* (I_PU = 10–30 µA) **during reset and before configuration**. Through R27+R28 that sources 10–30 µA into ≈101 kΩ → **EN_HIL ≈ 1.0–3.0 V**. The TPS259470L's EN/UVLO rising threshold is **1.183 / 1.20 / 1.223 V** (min/typ/max), so the node straddles the threshold: **U4 can enable at power-up and put VBUS on J3 before the service writes its defaults**, with the discharge FET off in that state.
- **Requirements violated:** architecture §1 "Deterministic default … U4 EN low and discharge on"; product §6 "On service start, GPIO outputs must be set to the disconnected state before any test is accepted".
- **The datasheet prescribes the fix:** "a strong pull-down (10 kΩ) can be used to ensure the pin remains low during reset". R28 is 10× too weak.
- **Fix:** `R28 = 10 kΩ` (keep R27 as the series element) → EN_HIL ≈ 0.3 V worst case.
- **What is correctly done:** `HIL_DATA_EN_N` and `HIL_CC_EN_N` are active-low, so their power-up default (high) *is* the safe state, and `R48`/`R49` = 100 kΩ provide explicit pull-ups. Only the inverted-logic enable needs the strong pull-down.
- **Evidence:** CP2102N §4.3.1 + Table 3.7 (I_PU 10–30 µA); TPS259470x Table 6-1 (V_UVLO(R) 1.183/1.20/1.223 V); extraction `R27 = 1k`, `R28 = 100k`. **Confidence: medium-high** — the outcome depends on the un-tightened weak pull-up value, which is precisely why the default cannot be guaranteed as designed.

---

### H5 — Three 10 kΩ resistors carried a 1 kΩ part number (the wrong part would have been fitted)
**Status: ✅ FIXED 2026-09-27.**
- **What:** `R33`, `R34` and `R35` all had `Value = 10k` but `LCSC = C11702`, which is **`0402WGF1001TCE` = 1 kΩ**. The 10 kΩ part is `0402WGF1002TCE` = C25744 — the two MPNs differ by a single digit, which is almost certainly how they were crossed.
- **Why it matters:** JLCPCB builds from the LCSC codes in the BOM, so all three would have been fitted as 1 kΩ, silently changing the design.
- **Impact by part:** `R33` is the TPS2121 `ST` pull-up — the datasheet specifies **R_ST = 6–20 kΩ**, so 1 kΩ is outside spec; `R34` is the `HIL_FLT_N` pull-up, where 1 kΩ instead of 10 kΩ raises the open-drain sink current from 0.33 mA to 3.3 mA (≈4.8 mA with LED3's path on the same node) — TI does not state the FLT pin's sink capability; `R35` (CH334F `~OVCUR#` pull-up) is insensitive to the change.
- **How it was found:** a whole-board cross-check of every `LCSC` property against its catalog value, run while applying the H2 fix — not visible to ERC or DRC.
- **Fix applied:** R33, R34 and R35 now carry `C25744` (10 kΩ ±1%, 0402, JLCPCB Basic).
- **Evidence:** JLCPCB catalog rows for C11702 (`0402WGF1001TCE`, 1 kΩ) and C25744 (`0402WGF1002TCE`, 10 kΩ); TPS2121 §10.2.3 and Table 7.3 (R_ST 6–20 kΩ). **Confidence: high.**

---

### H6 — Y1's 4-pad crystal was wired to a ground pad instead of XOUT (the hub could never have clocked)

**Status: ✅ FIXED 2026-09-27 (second pass).** Y1 now uses `Device:Crystal_GND24`, wired pin 1 → `Net-(U1-XI)`, pin 3 → `Net-(U1-XO)`, pins 2 and 4 → `GND`. Re-verified from the exported netlist: `Net-(U1-XI) = U1.4 + Y1.1`, `Net-(U1-XO) = U1.3 + Y1.3`, and `Y1.2`/`Y1.4` are on the `GND` net.
- **What:** `Y1` used the two-pin symbol `Device:Crystal` on the four-pad footprint `Crystal_SMD_3225-4Pin_3.2x2.5mm`. KiCad maps symbol pin *n* → footprint pad *n*, so the board connected `XI` → pad 1 and `XO` → pad 2, leaving pads 3 and 4 with **no net at all** (read directly out of the `.kicad_pcb` pad blocks).
- **Why it's wrong:** the four-pad SMD crystal pinout is **crystal terminals on pads 1 and 3, case/GND on pads 2 and 4**. Pad 2 is a *ground* pad and pad 3 — the real `XOUT` — was floating. The CH334F's oscillator was therefore connected between `XI` and a ground pad with `XOUT` open: **it would never have started, so the hub — and every USB path on the board — would have been dead.** ERC and DRC cannot see this; the netlist is syntactically valid.
- **Evidence (three independent textual sources, none of them a rendered drawing):**
  - **Lucki `L225S120U11L`** (SMD2520-4P) datasheet pin table: `#1 Xtal Terminal (Input)`, `#2 GND`, `#3 Xtal Terminal (Output)`, `#4 GND`.
  - **ECS `ECX-1048`** datasheet "PAD CONNECTIONS": `1 In/Out`, `2 NC`, `3 Out/In`, `4 Gnd` — same terminal pairing (1 and 3).
  - **KiCad's own library:** `Device:Crystal_GND24` is described as *"Four pin crystal, GND on pins 2 and 4"*, and the generic `Crystal_SMD_*4Pin*` footprints all share the identical quadrant pad numbering.
  - The TXC `7M` drawing that `Crystal_SMD_3225-4Pin_3.2x2.5mm` is traced from (URL in the footprint's own description field) shows the same arrangement.
- **Note on method:** an automated read of the *rendered* YXC drawing suggested pads 3 and 4 were ground, conflicting with all three textual sources; the vector drawing has no extractable text layer, so the textual pin tables were treated as authoritative. **Confidence: high.**
- **Fix:** `Device:Crystal_GND24`, pin 1 → XI, pin 3 → XO, pins 2 & 4 → GND. **Generalise the rule: a two-pin crystal symbol on a four-pad footprint is a latent wiring error** — it looks correct in the schematic and produces a valid netlist.
- **Secondary benefit:** grounding pads 2 and 4 also shields the case, which the floating version did not.
- **Related:** the three dead `Datasheet` fields (M7) and C5's value/part mismatch (M11) are siblings of this class — an attribute that is not checked by any automated tool.

---

### H7 — The architecture's GPIO map contradicted the schematic on 6 of 7 pins; following it would have left U4 disabled and J3 unable to advertise

**Status: ✅ FIXED 2026-09-28 — documentation corrected, no schematic or board change.** `architecture_final.md` §6.1 (table), the `cp2102n_config.hex` release-gate instruction, the two stale GPIO references in §5.1/§5.2, the non-existent `GPIO.7` claim in §5.1, and `schematic_overview.md` now all match the netlist, and the configuration image is specified to be generated from the netlist rather than from the prose. §6 was also expanded with a configuration-image manifest (§6.3) and a corrected control-service example (§6.4, which also had broken indentation). Verified programmatically: the document's seven pin→net rows now agree with the board 7/7, and each declared mode matches its net's role.

This is a *contract* defect rather than a wiring defect, but its consequence is a fixture that does not work — and it is invisible to ERC and DRC, because no automated check compares a document to a netlist.

- **What:** the CP2102N's actual pin allocation, read from the exported netlist's `pinfunction` values and their nets:

| CP2102N pin | Pin function | Net in the schematic | `architecture_final.md` §6 says |
|---:|---|---|---|
| 19 | `~TXT`/GPIO.0 | `HIL_FLT_N` | `HIL_FLT_N` ✅ |
| 18 | `~RXT`/GPIO.1 | `VBUS_HIL_SNS` | `VBUS_PWR_SNS` ✗ |
| 17 | `RS485`/GPIO.2 | `HIL_CC_EN_N` | `VBUS_HIL_SNS` ✗ |
| 16 | `~WAKEUP`/GPIO.3 | `VBUS_PWR_SNS` | `VBUS_UP_SNS` ✗ |
| 22 | GPIO.4 | `HIL_DATA_EN_N` | `HIL_VBUS_EN` ✗ |
| 21 | GPIO.5 | `VBUS_UP_SNS` | `HIL_DATA_EN_N` ✗ |
| 20 | GPIO.6 | `HIL_VBUS_EN` | `HIL_CC_EN_N` ✗ |

- **Why it matters:** `architecture_final.md` §6 — echoed by the release-gate instruction to *"Program CP2102N with Silicon Labs Xpress Configurator … GPIO.4 push-pull reset low; GPIO.5/6 open-drain reset high; GPIO.0-3 digital inputs"* and to ship a `cp2102n_config.hex` generated from that manifest — tells the programmer to make **GPIO.0–3 inputs, GPIO.4 a push-pull output and GPIO.5/6 open-drain outputs**. Applied to *this* hardware, three pins receive a functionally wrong mode:
  - **pin 20 (`GPIO.6`) = `HIL_VBUS_EN`, configured open-drain.** `HIL_VBUS_EN` reaches `EN_HIL` through `R27` (1 kΩ) with `R28` (10 kΩ) to GND, so enabling U4 requires the pin to **drive high** past the TPS259470L's 1.20 V UVLO threshold. An open-drain output cannot drive high, so `EN_HIL` stays at ≈0 V and **U4 never enables — no DUT power is ever delivered.** The push-pull assignment lands instead on pin 22 (`HIL_DATA_EN_N`), where it is harmless.
  - **pin 17 (`GPIO.2`) = `HIL_CC_EN_N`, configured as an input.** As an input it cannot drive, so `R49` (100 kΩ) holds U6's `!OE` high → U6's output is high-Z → `VRP_3A` floats → **no Rp reaches `J3_CC1`/`J3_CC2`, so J3 never advertises power and the DUT never comes up.**
  - **pin 21 (`GPIO.5`) = `VBUS_UP_SNS`, configured as an open-drain output.** That pin reads the `R73`/`R74` 100 kΩ divider, so driving it as an output clamps or corrupts the J1-present sense.
- **Which side is wrong: the schematic is right and the architecture is wrong.** The wiring is self-consistent with the intent — the two pins that must be open-drain outputs (`HIL_DATA_EN_N`, `HIL_CC_EN_N`) each carry a 100 kΩ pull-up (`R48`, `R49`), the pin that must be push-pull (`HIL_VBUS_EN`) drives a series-resistor/threshold path with no pull-up, and the four sense nets drive dividers into the chip. Only the *assignments* differ from §6.
- **Fix:** correct the §6 table, the `cp2102n_config.hex` instruction and the `schematic_overview.md` block diagram to the map above, then derive the configuration image from the **netlist** rather than from the document. Nothing needs to change on the schematic or the board.
- **Why it was missed until now:** the earlier reviews verified that the architecture's GPIO table was internally consistent and that each net was wired as its name implies — which is exactly what hides a pin-level permutation. Both the document and the net names are self-consistent; only their *pairing* is wrong.
- **Collateral fix found while editing the same document: its §9 BOM passive table was stale in the H5/M11 class.** It listed **two parts that do not exist** (`R7`/`R8`, 5.6 kΩ, C25908) and carried pre-fix values for `R28` (100 kΩ — H4 changed it to 10 kΩ), `R34` (1 kΩ in the 1 kΩ group — H5 changed it to 10 kΩ), `R5`/`R6` (33 kΩ, C25779 — the fitted part is 4.7 kΩ, C25900), `C23`/`C25` (1 µF — M2 changed them to 4.7 µF C1779) and `C5`/`C37` (C37 does not exist). Because this is the table someone would **order from**, it was regenerated from the design and now expands to exactly the schematic's 36 resistors and 23 capacitors — verified: 59 references, 0 problems, none missing. Worth noting that the v2/v3 whole-board value/part cross-checks never covered this document, only the schematic.
- **Evidence:** netlist `pinfunction` values for U2 with their net membership (exported 2026-09-27); `architecture/architecture_final.md` §6 and the release-gate instruction; `architecture/schematic_overview.md`; net membership of `R27`, `R28`, `R48`, `R49`, `R73`, `R74`; U6 (`SN74LVC1G125`) pin 1 = `!OE`. **Confidence: high** for the mismatch and for all three mode consequences.

#### Was a pin shuffle worth doing? Measured, not assumed

With the document confirmed wrong, the alternative was to change the *hardware* — either to the document's map, or to a routing-optimal one. All 5040 assignments of the seven signals to pins 16–22 were scored against the placed board on first-hop length and on fan-out **crossings** (a crossing costs a via or a detour, so it matters more than a millimetre):

| Assignment | Total first-hop length | Crossings |
|---|---:|---:|
| **as built** (schematic and board) | 52.32 mm | **0** |
| architecture §6 as it stood (adopting it would mean rewiring) | 55.07 mm | **2** |
| best of all 5040 permutations | 51.68 mm | 0 |

So the existing wiring is already crossing-free — the minimum achievable, shared by many permutations — and within **0.64 mm (1.2%)** of the global length optimum. The spread is small because most of each net's length lies outside U2's fan-out; the pin choice only affects the first hop. Adopting the document's map would have been a **regression: 2.75 mm longer and two crossings.** **No pin swap was made.**

Two further conclusions from the same measurement:

- The CP2102N pinout is **not** why 30 nets remain unrouted — that is a placement/routing problem, so the pin map should not be expected to buy routing headroom.
- The recommendation is tied to the current placement. If the divider networks, test points, U4, U5 or U6 are moved, the optimum can shift — but with only ~1 mm of total spread across all 5040 options it is unlikely to become worth a rewire.

**Method (so the numbers can be re-derived):** pad geometry was computed from the `.kicad_pcb` with the rotation transform `abs = fp + (lx·cos θ + ly·sin θ, −lx·sin θ + ly·cos θ)`, validated against **23/23** absolute pad coordinates printed by `kicad-cli pcb drc`. The first validation attempt failed because pad numbers like `SH` exist **four times** in a USB-C footprint (and an exposed pad with thermal vias exists many times) — a parser that keys pads by number alone silently keeps only the last instance and produces mirrored geometry. Worth remembering for any future board-side script.

---

## Medium findings

### M1 — J2 mixed a 16-pin USB-C symbol with a 6-pin footprint (silent pin/pad mismatch)
**Status: ✅ FIXED 2026-09-27.** J2 now uses `Connector:USB_C_Receptacle_PowerOnly_6P`, whose seven pins (`A5`, `B5`, `A9`, `B9`, `A12`, `B12`, `SH`) map one-to-one onto the C283540 footprint. Verified from the exported netlist: J2's VBUS pins sit on `VBUS_PWR`, its CC pins on `J2_CC1`/`J2_CC2`, and `A12`/`B12`/`SH` on `GND` — no phantom pins, nothing left dangling. ERC's `lib_symbol_mismatch` warning for J2 is gone (only J1's remains).
- **What it was:** `J2` used `Connector:USB_C_Receptacle_USB2.0_16P` (pins A1, A4, A5, A6–A9, B1, B4, B5, B6–B9, A12, B12, SH) with footprint `Connector_USB:USB_C_Receptacle_HRO_TYPE-C-31-M-17`, whose pads are only **A5, B5, A9, B9, A12, B12, SH**. Symbol pins **A1/A4/B1/B4 had no pad** → silently unconnected. It happened to work (every *connected* pin mapped), but the mismatch was invisible because ERC's "Assigned footprint doesn't match footprint filters" check is **globally disabled** (M3).
- **Consequence that had to be fixed alongside it:** the old 16-pin symbol carried a `power_out` pin on VBUS. The new 6-pin symbol has **passive** VBUS pins, so `VBUS_PWR` lost its driver and now raises a new `power_pin_not_driven` error — see M3. That is expected, and a `PWR_FLAG` on `VBUS_PWR` closes it.
- **Evidence:** pad list read from `Connector_USB.pretty/USB_C_Receptacle_HRO_TYPE-C-31-M-17.kicad_mod`; current netlist export; current ERC report. **Confidence: high.**

### M2 — CP2102N decoupling was below the datasheet requirement
**Status: ✅ FIXED 2026-09-27 (values). ⚠️ Placement still open.** The CP2102N note — *"4.7 µF and 0.1 µF bypass capacitors required for each power pin **placed as close to the pins as possible**"* — appears on Figures 2.1, 2.2 **and** 2.3. This design is the Figure 2.3 arrangement (internal regulator unused: VDD and VREGIN both on the 3.3 V rail).

| Pin | Requires | Now | |
|---|---|---|---|
| VDD (6) | 4.7 µF + 0.1 µF | C23 = 4.7 µF **C1779** (0805) + C24 = 100 nF (0402) | ✅ |
| VREGIN (7) | 4.7 µF + 0.1 µF | C25 = 4.7 µF **C1779** (0805) + C28 = 100 nF (0402, newly added) | ✅ |

- **What it was:** `C23 = 1 µF` + `C24 = 100 nF` on VDD; `C25 = 1 µF` on VREGIN with **no** 0.1 µF at all.
- **Why the chosen part is the better outcome:** the 4.7 µF part is `C1779` — **JLCPCB Basic**, already used at C1/C3 — and 0805 rather than a smaller 0603. That gives one unique 4.7 µF line in the BOM instead of two, **no extended-part setup fee**, and less DC-bias derating than a 0603 X5R 4.7 µF/25 V at 5 V. The 0.1 µF caps stay 0402, which is correct for HF decoupling.
- **Still open — placement.** Measured on the PCB, all four caps sat **5.9–6.6 mm** from U2 pads 6/7 (C24 5.88 mm, C28 6.58 mm at the last measurement), against a ≤3 mm target for the 100 nF parts. U2 is a 135°-rotated QFN-28 whose power pins face a region occupied by the R70–R75 dividers and TP10/TP15, so the caps ended up on the far side of the package. **Re-verify after the current placement pass** — the area immediately outward of pins 6/7 (≈160.5, 110.5) is where the two 100 nF parts belong, with the bulk within ~5 mm.
- **Evidence:** CP2102N §2.1 + Figures 2.1–2.3 (note text confirmed identical on all three); JLCPCB catalogue rows for C1779/C52923/C1525; PCB pad-coordinate measurement. **Confidence: high** (requirement and values); **medium** (placement, being a layout property).
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

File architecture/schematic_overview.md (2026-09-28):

# Schematic overview

This is an implementation map for the final reviewed architecture. It does not replace [`architecture_final.md`](architecture_final.md), which is the source for exact values, part numbers, and validation gates.

## Net-level block topology

```mermaid
flowchart LR
  J1[J1 USB-C upstream] -->|D+/D-/GND| U1[U1 CH334F USB 2.0 hub]
  J1 -->|VBUS_UP| U14
  J2[J2 USB-C 5 V power] -->|VBUS_PWR / preferred| U14[U14 TPS2121RUXR]
  U14 -->|VSYS| U4[U4 TPS259470L]
  U4 -->|VBUS_HIL| J3[J3 USB-C DUT]
  U1 -->|Port 1| U2[U2 CP2102N]
  U1 -->|Port 2| U5[U5 TS3USB221A]
  U5 -->|D+/D-| J3
  U2 -->|GPIO.6 HIL_VBUS_EN| U4
  U2 -->|GPIO.4 HIL_DATA_EN_N| U5
  U2 -->|GPIO.2 HIL_CC_EN_N| U6[U6 SN74LVC1G125]
  U6 -->|fixed 3 A Rp| J3
  U14 --> U8[U8 3.3 V LDO]
  U8 --> U1
  U8 --> U2
  U8 --> U5
  U8 --> U6
```

## Sheet / placement partitions

| Partition | Contents | Critical routing / placement rule |
|---|---|---|
| J1 upstream and hub | J1, U9, U1, Y1, Q6/Q7 | Keep USB pairs short and 90 Ohm differential. Keep Y1 away from high-current copper. |
| Power entry and priority | J2, input TVS, U14, U8 | J2 is U14 IN2; J1 is IN1. Strap PR1 to GND and CP2 to J2 VBUS. Keep VSYS copper wide and U14 thermal vias under pad. |
| HIL output | U4, C9-C13, Q2/Q3, R36, J3 VBUS | Put input/output capacitors at U4 pins. Keep the VBUS_HIL and discharge loop compact. |
| DUT data and CC | U5, U6, U10, Rp resistors, J3 | Keep U5 USB routing continuous and short. Place U10 directly behind J3. Keep CC traces away from D+/D-. |
| Control and test | U2, sense dividers, FLT pull-up, test points | Bring all enables, senses, ILM, FLT, VSYS and both input VBUS nets to labelled test points. |

## PCB floor plan

- Left edge: J1; then U9 and U1/Y1 toward the left-center.
- Top edge: J2, input TVS, U14 and its VSYS bulk capacitors.
- Top-right: U4, output capacitors and the Q2/Q3 discharge loop.
- Right edge: J3 with U10 immediately behind it; U5/U6 between U1 and J3.
- Bottom-center: U2; place U8 next to its 3.3 V loads.
- L2 is solid ground. L3 carries VSYS and VBUS_HIL pours. Use a JLC-selected four-layer stack-up and its calculated 90 Ohm USB differential geometry.

## Build gates

- No KiCad files are included in this package.
- Use the exact component selections and pin-level constraints in [`architecture_final.md`](architecture_final.md).
- Prototype/production validation gates remain mandatory before release: CP2102N configuration/read-back, CH334F reset behavior, U14 reverse current, 3 A thermal/load-step behavior, J2 source compatibility, and ESD robustness.

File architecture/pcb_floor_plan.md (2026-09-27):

# Preliminary PCB Floor Plan

Top-view preliminary PCB floor plan

## Size estimate

Use a **75 x 50 mm** rectangular four-layer outline for the first layout. This is a planning estimate, not a released mechanical dimension.

The existing 60 x 40 mm target is physically possible only if the connector footprints, chosen four-layer impedance stack-up, thermal spreading, and full routing all fit without compromises. It is a compact variant to evaluate after placement. The 75 x 50 mm starting outline leaves useful margin for the 3 A path, thermal copper around U14/U4, accessible test pads, and controlled-impedance USB routing.

| Outline | Area | Status |
|---|---:|---|
| 60 x 40 mm | 2,400 mm2 | Original compact target; high placement and thermal risk |
| **75 x 50 mm** | **3,750 mm2** | **Recommended initial layout estimate** |

## Placement intent

- **Left short edge:** J2 occupies the upper position and J1 the lower position. J2 feeds U14 `IN2` through a short, wide preferred-power path; J1 VBUS feeds U14 `IN1` through a separate wide fallback-power path, while J1 D+/D- pass through their ESD array to the hub (U1).
- **Upper-left interior:** U14 stays beside J2, with enough copper and thermal vias for the priority-mux heat spreading. Keep the J2 power path separate from the J1 USB pair.
- **Right edge:** U5, U10, and J3 form the switched downstream USB path. Put the Rp buffer and resistor network close to J3 CC pins.
- **Upper-right:** U4, its input/output capacitors, output TVS, and the Q2/Q3/R36 discharge circuit. Place the discharge components next to U4 OUT, not near the USB path.
- **Lower center:** U2 and its low-speed GPIO/sense network. U8 sits between the power and 3.3 V load clusters, with local bypass capacitors at every IC.
- **Bottom edge:** Accessible test pads. Keep USB pair probe vias separate from power and GPIO test pads.
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

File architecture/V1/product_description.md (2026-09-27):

Product: HIL USB-C control

Scope design a pcb for HIL test, with power and data control of signals
The device should manage the power and data lines to the HIL test device based on the control signals received from the Raspberry Pi.
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

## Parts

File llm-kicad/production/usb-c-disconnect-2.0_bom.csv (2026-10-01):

Designator | Footprint | Quantity | Value | LCSC Part #
C1, C23, C25, C3 | 0805 | 4 | 4.7uF 25V | C1779
C10, C13, C20, C22, C24, C26, C27, C28, C6 | 0402 | 9 | 100nF | C1525
C11, C12, C9 | 0805 | 3 | 10uF 25V | C15850
C14 | 0402 | 1 | 1nF | C1523
C16 | 0402 | 1 | 1uF 0402 25V | C52923
C17 | 0805 | 1 | 10uF 0805 25V | C15850
C18 | 0402 | 1 | 100nF 0402 | C1525
C19, C21 | 0402 | 2 | 1uF 25V | C52923
C2 | 0402 | 1 | 100pF | C1546
C5 | 1206 | 1 | 47uF 10V | C96123
D1, D2, D3 | D_SMA | 3 | SMAJ6.5A | C123817
H1, H2, H3, H4 | MountingHole_2.2mm_M2 | 4 | MountingHole
J1, J3 | USB_C_Receptacle_HRO_TYPE-C-31-M-12 | 2 | TYPE-C-31-M-12 | C165948
J2 | USB_C_Receptacle_HRO_TYPE-C-31-M-17 | 1 | TYPE-C-31-M-17 | C283540
J4 | PinHeader_1x02_P2.54mm_Vertical | 1 | Conn_01x02_Socket
LED1 | 0805 | 1 | Green | C2297
LED2 | 0805 | 1 | Yellow | C2296
LED3 | 0603 | 1 | Red | C2286
Q2, Q3, Q6, Q7 | SOT-23 | 4 | BSS138P,215 | C75547
R1, R2 | 0402 | 2 | 5.1k | C25905
R27, R47, R50, R51, R52 | 0402 | 5 | 1k | C11702
R28, R33, R34, R35 | 0402 | 4 | 10k | C25744
R29 | 0402 | 1 | 49.9k | C25897
R3, R4 | 0402 | 2 | 5.1k 0402 | C25905
R30 | 0402 | 1 | 12k | C25752
R31 | 0402 | 1 | 931R 0.1% | C852955
R32 | 0402 | 1 | 24k | C25769
R36 | 0805 | 1 | 470R 0805 | C17710
R37 | 0402 | 1 | 100k 0402 | C25741
R38, R79 | 0402 | 2 | 10k 0402 | C25744
R39 | 0402 | 1 | 18k 0402 | C25762
R40 | 0402 | 1 | 1k 0402 | C11702
R43 | 0402 | 1 | 22k | C25768
R44 | 0402 | 1 | 47k | C25792
R45, R46, R48, R49 | 0402 | 4 | 100k | C25741
R5, R6 | 0402 | 2 | 4.7k | C25900
R76 | 0402 | 1 | 330R 0402 | C25104
TP1 | TestPoint_Pad_D1.5mm | 1 | VBUS_UP
TP10 | TestPoint_Pad_D1.5mm | 1 | HIL_VBUS_EN
TP11 | TestPoint_Pad_D1.5mm | 1 | HIL_DATA_EN_N
TP12 | TestPoint_Pad_D1.5mm | 1 | HIL_CC_EN_N
TP14 | TestPoint_Pad_D1.5mm | 1 | VBUS_HIL_SNS
TP16 | TestPoint_Pad_D1.5mm | 1 | EXT_02
TP2 | TestPoint_Pad_D1.5mm | 1 | VBUS_PWR
TP3 | TestPoint_Pad_D1.5mm | 1 | VSYS
TP4 | TestPoint_Pad_D1.5mm | 1 | +3V3
TP5 | TestPoint_Pad_D2.0mm | 1 | VBUS_HIL
TP7 | TestPoint_Pad_D1.5mm | 1 | U4_ILM
TP8 | TestPoint_Pad_D1.5mm | 1 | EN_HIL
TP9 | TestPoint_Pad_D1.5mm | 1 | EXT_I01
U1 | QFN-24-1EP_4x4mm_P0.5mm_EP2.7x2.7mm | 1 | CH334F | C5187527
U10, U3, U9 | USON-10_2.5x1.0mm_P0.5mm | 3 | TPD4E05U06DQA | C138714
U11 | USON-10_2.5x1.0mm_P0.5mm | 1 | TPD4E05U06DQAR | C138714
U14 | Texas_VQFN-HR-12_2x2.5mm_P0.5mm | 1 | TPS2121RUXR | C485916
U15 | SOP-4_4.4x2.6mm_P1.27mm | 1 | LTV-217 | C115450
U2 | QFN-28-1EP_5x5mm_P0.5mm_EP3.25x3.25mm | 1 | CP2102N-A02-GQFN28 | C964632
U4 | TPS259470LRPWR | 1 | TPS259470LRPWR | C3662793
U5 | Texas_UQFN-10_1.5x2mm_P0.5mm | 1 | TS3USB221A | C128396
U6 | SOT-23-5 | 1 | SN74LVC1G125DBVR | C23654
U8 | WSON-6-1EP_2x2mm_P0.65mm_EP1x1.6mm_ThermalVias | 1 | TLV76733DRVR | C2848334
Y1 | Crystal_SMD_3225-4Pin_3.2x2.5mm | 1 | Crystal 12MHz | C9002

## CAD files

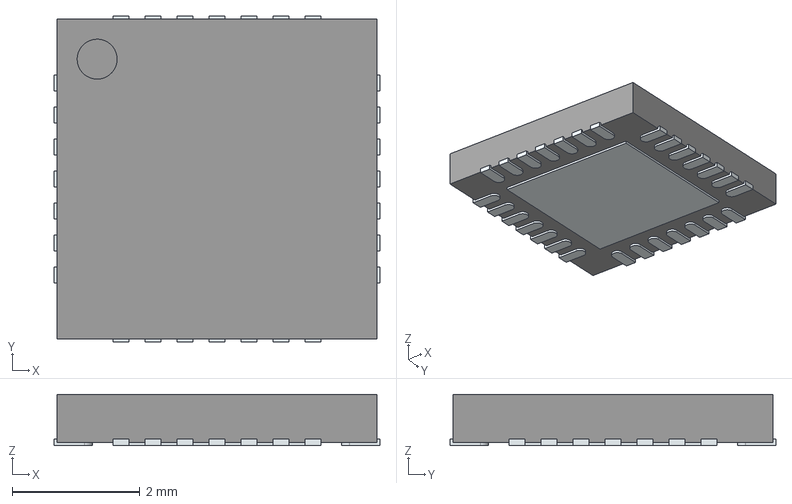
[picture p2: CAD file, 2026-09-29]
llm-kicad/symbols/CP2102N-A02-GQFN28R/3D/CP2102N-A02-GQFN28R.stp
5.10 x 5.10 x 0.8 mm
ThermalPin
PinsArrayLR
PinsArrayTB

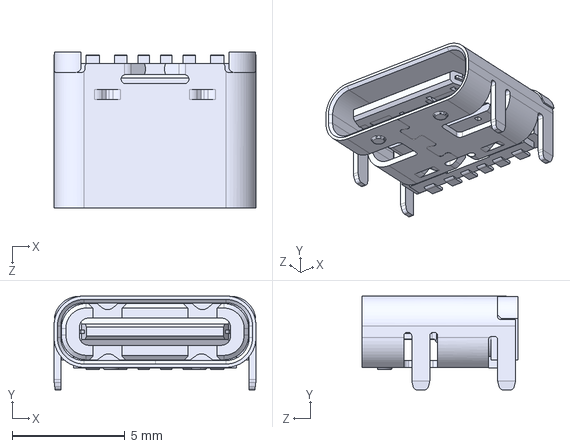
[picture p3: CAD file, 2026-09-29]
llm-kicad/symbols/UJC-H-G-SMT-P6-TR.stp
8.94 x 4.16 x 6.90 mm

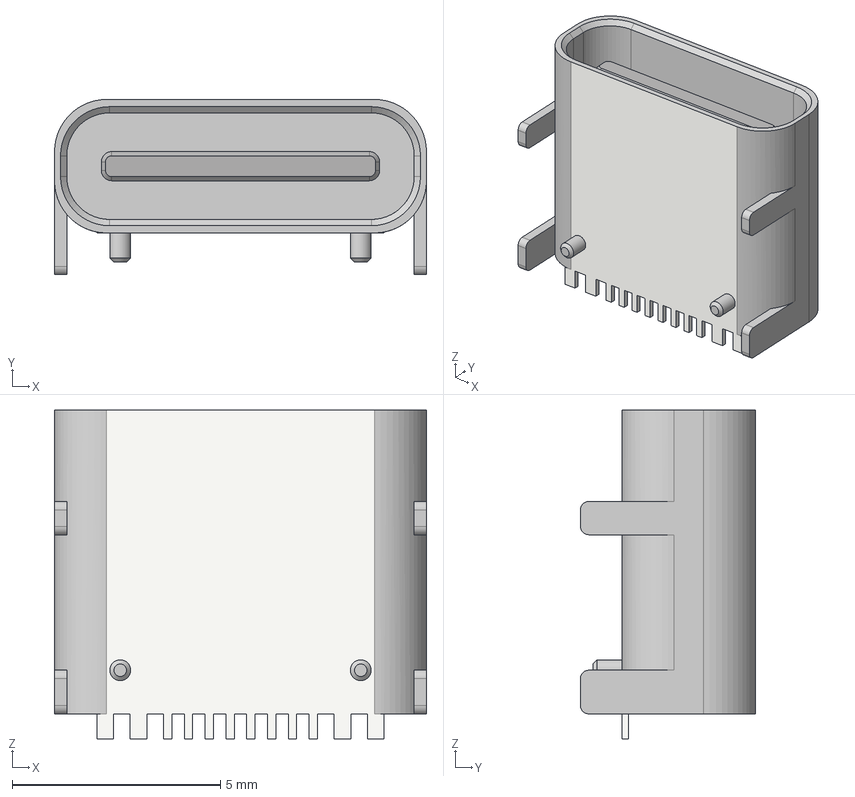
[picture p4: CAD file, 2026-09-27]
llm-kicad/symbols/USB_C_Receptacle_HRO_TYPE-C-31-M-12.step
8.94 x 4.21 x 7.90 mm

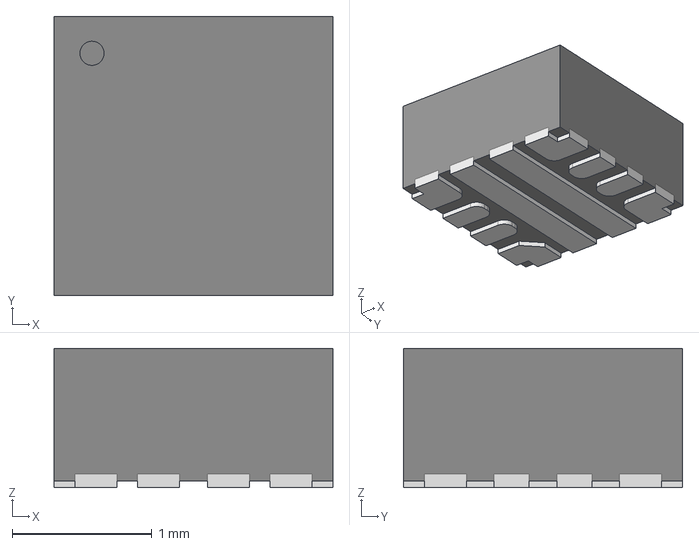
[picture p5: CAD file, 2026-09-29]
llm-kicad/symbols/TPS259470LRPWR/3D/TPS259470LRPWR.stp
2.00 x 2.00 x 1.00 mm

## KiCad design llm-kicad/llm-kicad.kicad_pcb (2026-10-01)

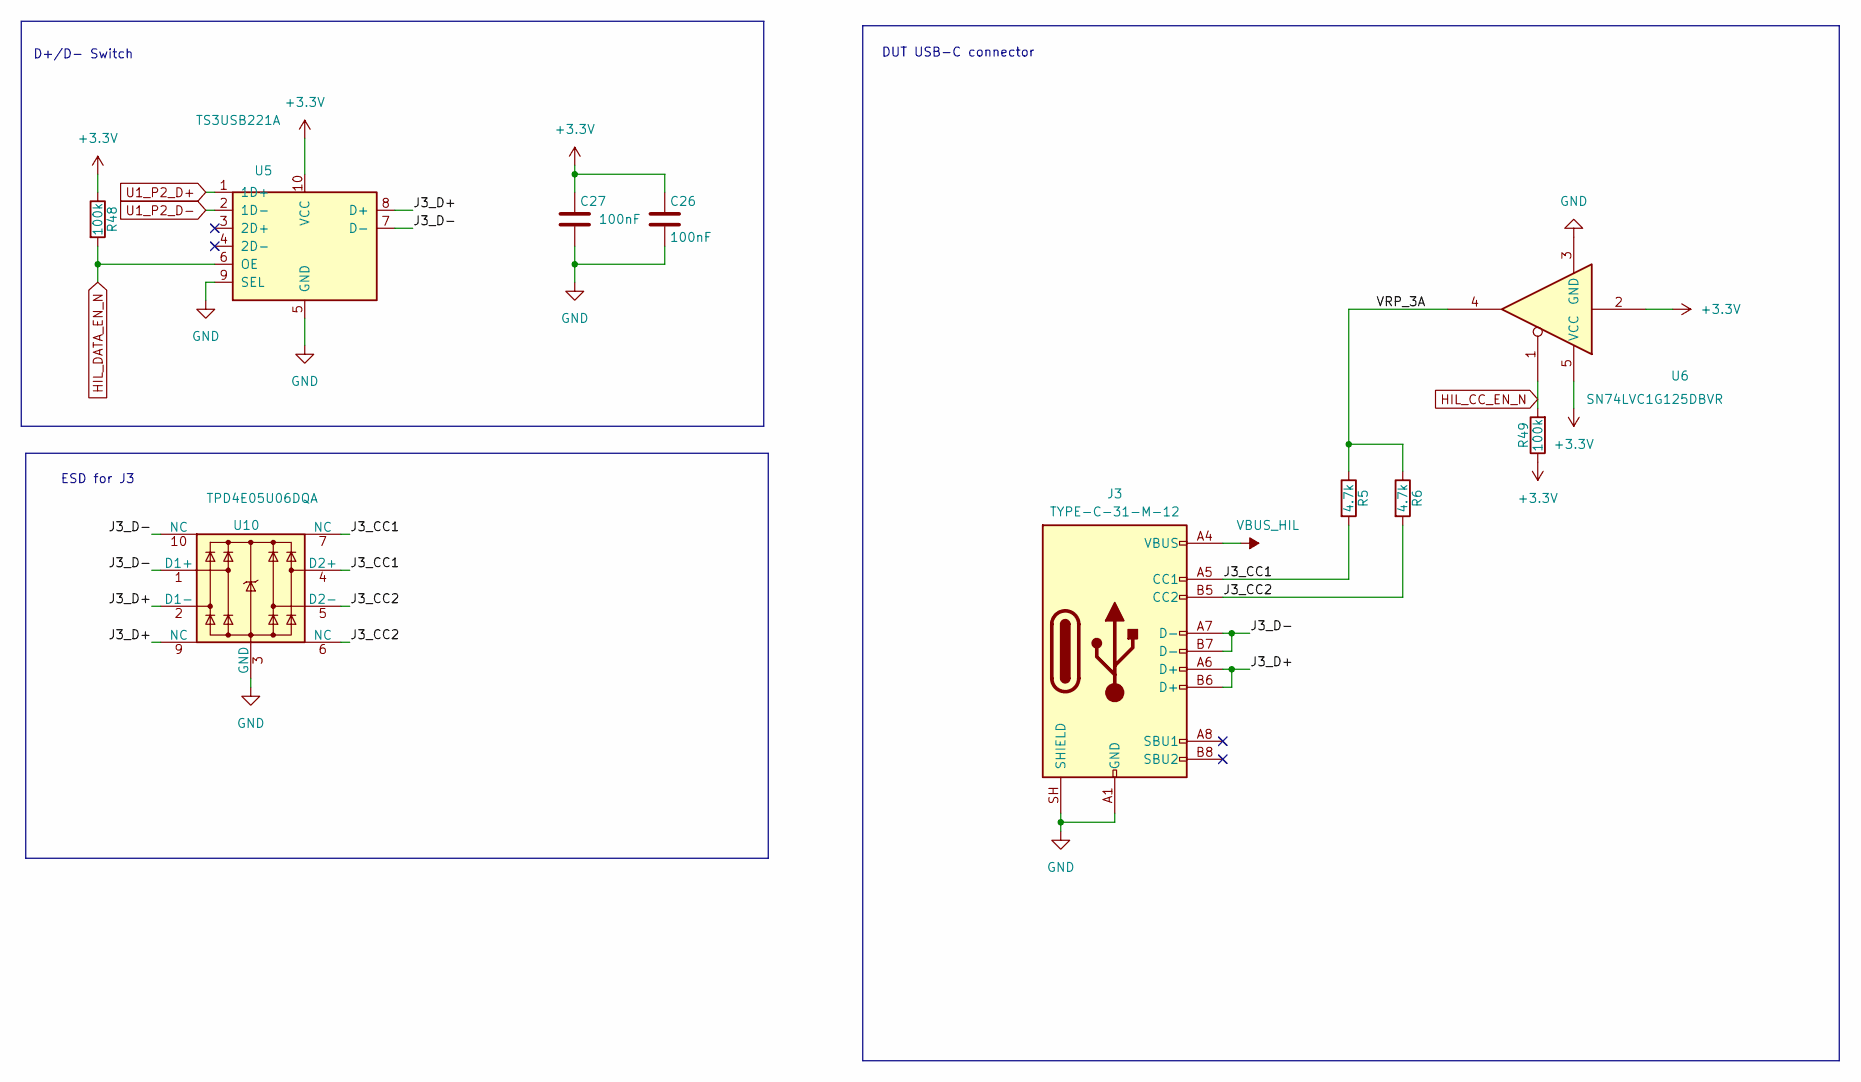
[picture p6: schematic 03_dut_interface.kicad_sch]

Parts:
C26, C27: 100nF; C_0402_1005Metric; LCSC C1525
J3: TYPE-C-31-M-12; USB_C_Receptacle_HRO_TYPE-C-31-M-12; LCSC C165948
R5, R6: 4.7k; R_0402_1005Metric; LCSC C25900
R48, R49: 100k; R_0402_1005Metric; LCSC C25741
U5: TS3USB221A; Texas_UQFN-10_1.5x2mm_P0.5mm; LCSC C128396
U6: SN74LVC1G125DBVR; SOT-23-5; LCSC C23654
U10: TPD4E05U06DQA; USON-10_2.5x1.0mm_P0.5mm; LCSC C138714

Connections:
+3.3V: C26.1, C27.1, R48.1, R49.1, U5.10 (VCC), U6.2, U6.5 (VCC); also elsewhere on the board
/DUT Interface/J3_CC1: J3.A5 (CC1), R5.2, U10.4 (D2+), U10.7 (NC)
/DUT Interface/J3_CC2: J3.B5 (CC2), R6.2, U10.5 (D2-), U10.6 (NC)
/DUT Interface/J3_D+: J3.A6 (D+), J3.B6 (D+), U5.8 (D+), U10.2 (D1-), U10.9 (NC)
/DUT Interface/J3_D-: J3.A7 (D-), J3.B7 (D-), U5.7 (D-), U10.1 (D1+), U10.10 (NC)
/DUT Interface/VRP_3A: R5.1, R6.1, U6.4
GND: C26.2, C27.2, J3.A1 (GND), J3.A12 (GND), J3.B1 (GND), J3.B12 (GND), J3.SH (SHIELD), U5.5 (GND), U5.9 (SEL), U6.3 (GND), U10.3 (GND), U10.8 (GND); also elsewhere on the board
HIL_CC_EN_N: R49.2, U6.1; also elsewhere on the board
HIL_DATA_EN_N: R48.2, U5.6 (OE); also elsewhere on the board
U1_P2_D+: U5.1 (1D+); also elsewhere on the board
U1_P2_D-: U5.2 (1D-); also elsewhere on the board
VBUS_HIL: J3.A4 (VBUS), J3.A9 (VBUS), J3.B4 (VBUS), J3.B9 (VBUS); also elsewhere on the board

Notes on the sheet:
DUT USB-C connector
ESD for J3
D+/D- Switch

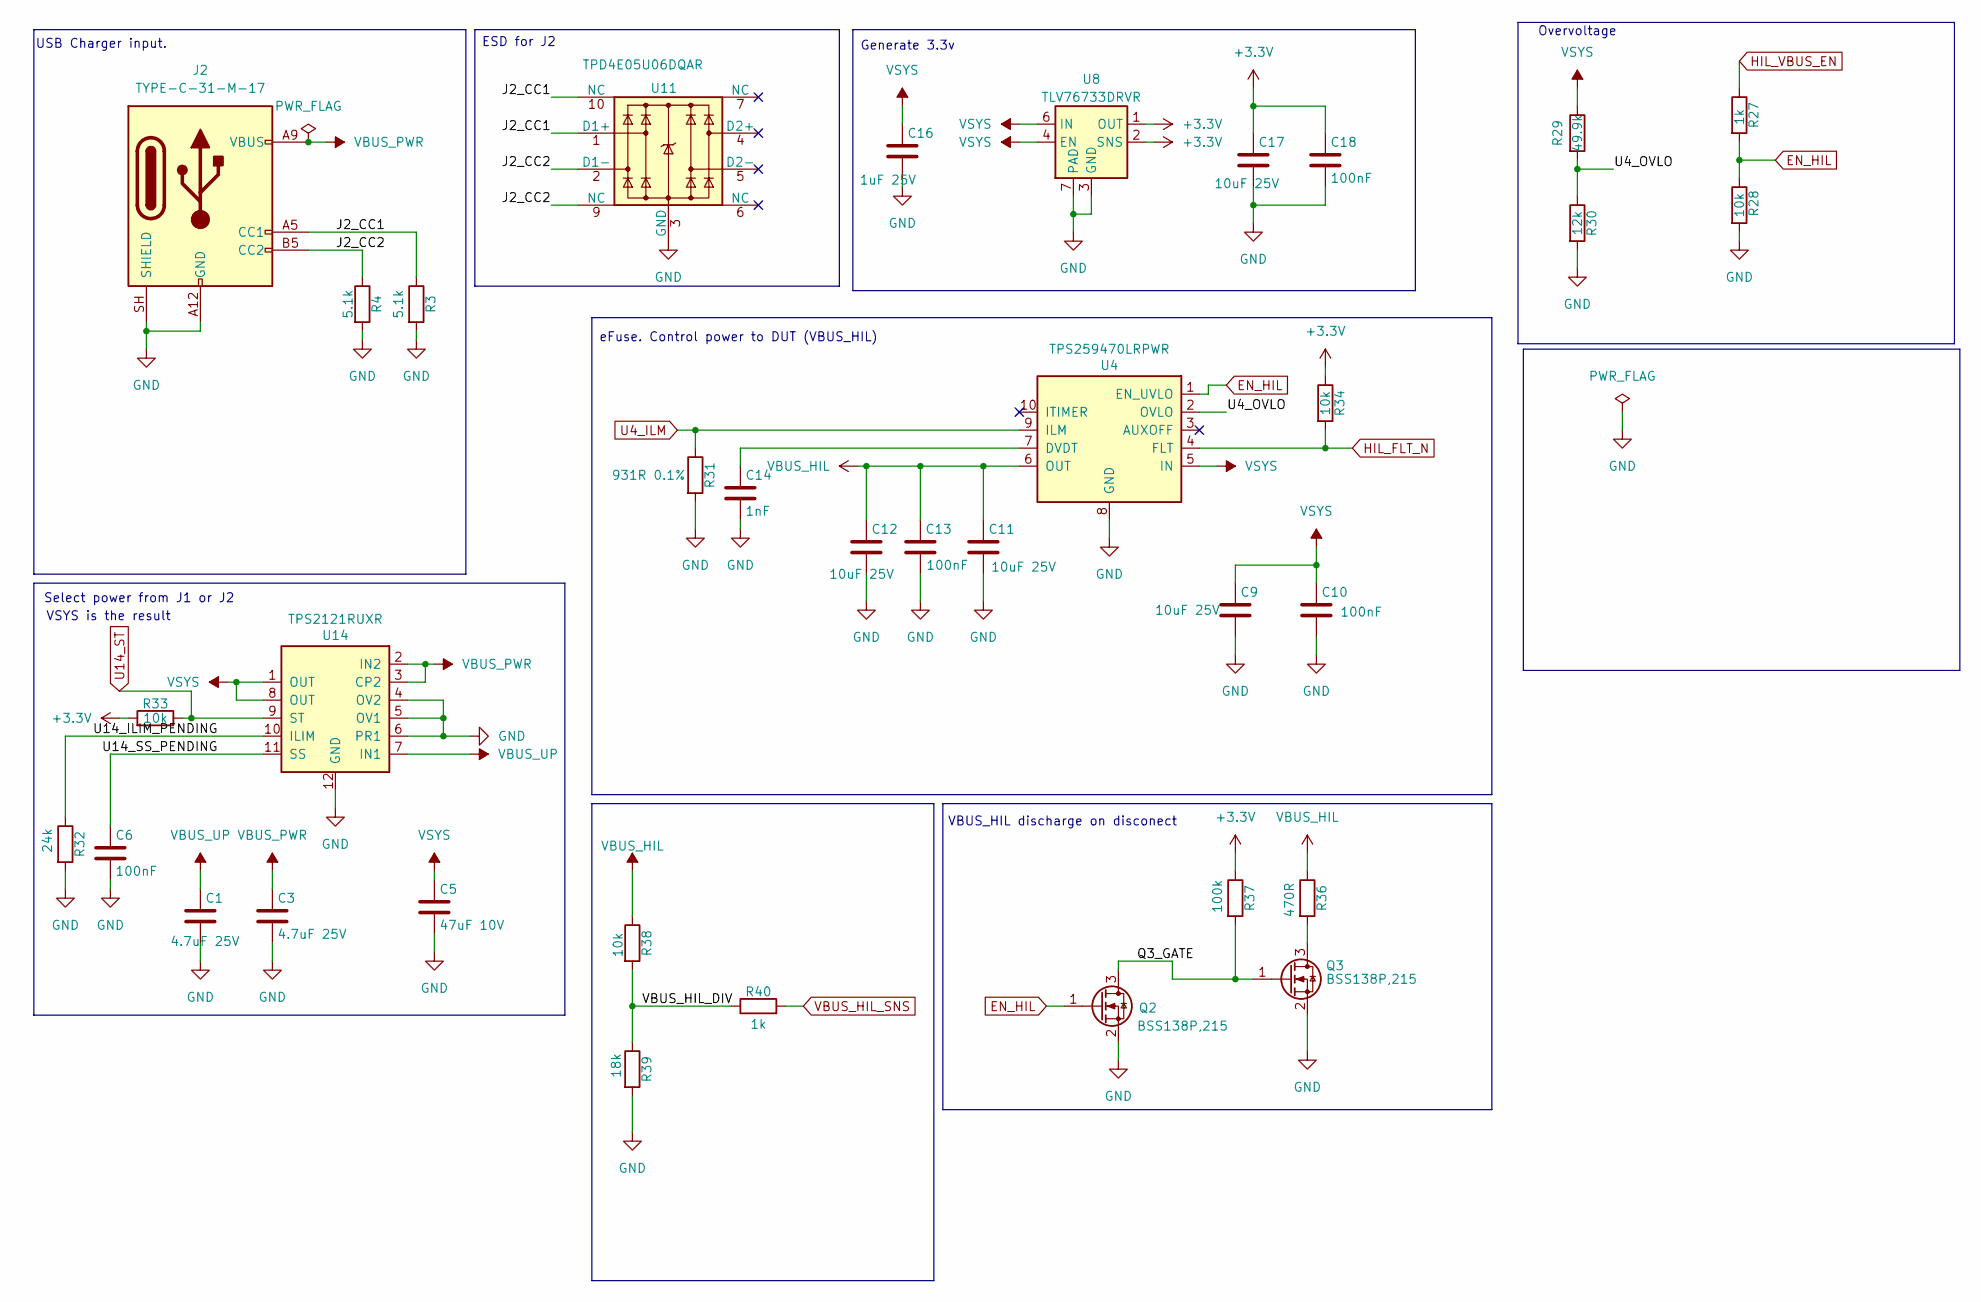
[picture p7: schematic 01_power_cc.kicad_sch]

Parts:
C1, C3: 4.7uF 25V; C_0805_2012Metric; LCSC C1779
C5: 47uF 10V; C_1206_3216Metric; LCSC C96123
C6, C10, C13, C18: 100nF; C_0402_1005Metric; LCSC C1525
C9, C11, C12, C17: 10uF 25V; C_0805_2012Metric; LCSC C15850
C14: 1nF; C_0402_1005Metric; LCSC C1523
C16: 1uF 25V; C_0402_1005Metric; LCSC C52923
J2: TYPE-C-31-M-17; USB_C_Receptacle_HRO_TYPE-C-31-M-17; LCSC C283540
Q2, Q3: BSS138P,215; SOT-23; LCSC C75547
R3, R4: 5.1k; R_0402_1005Metric; LCSC C25905
R27, R40: 1k; R_0402_1005Metric; LCSC C11702
R28, R33, R34, R38: 10k; R_0402_1005Metric; LCSC C25744
R29: 49.9k; R_0402_1005Metric; LCSC C25897
R30: 12k; R_0402_1005Metric; LCSC C25752
R31: 931R 0.1%; R_0402_1005Metric; LCSC C852955
R32: 24k; R_0402_1005Metric; LCSC C25769
R36: 470R; R_0805_2012Metric; LCSC C17710
R37: 100k; R_0402_1005Metric; LCSC C25741
R39: 18k; R_0402_1005Metric; LCSC C25762
U4: TPS259470LRPWR; LCSC C3662793
U8: TLV76733DRVR; WSON-6-1EP_2x2mm_P0.65mm_EP1x1.6mm_ThermalVias; LCSC C2848334
U11: TPD4E05U06DQAR; USON-10_2.5x1.0mm_P0.5mm; LCSC C138714
U14: TPS2121RUXR; Texas_VQFN-HR-12_2x2.5mm_P0.5mm; LCSC C485916

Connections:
+3.3V: C17.1, C18.1, R33.2, R34.1, R37.1, U8.1 (OUT), U8.2 (SNS); also elsewhere on the board
/Power and CC/J2_CC1: J2.A5 (CC1), R3.1, U11.1 (D1+), U11.10 (NC)
/Power and CC/J2_CC2: J2.B5 (CC2), R4.1, U11.2 (D1-), U11.9 (NC)
/Power and CC/Q3_GATE: Q2.3 (D), Q3.1 (G), R37.2
/Power and CC/U4_OVLO: R29.2, R30.1, U4.2 (OVLO)
/Power and CC/U14_ILIM_PENDING: R32.1, U14.10 (ILIM)
/Power and CC/U14_SS_PENDING: C6.1, U14.11 (SS)
/Power and CC/VBUS_HIL_DIV: R38.2, R39.1, R40.1
EN_HIL: Q2.1 (G), R27.2, R28.1, U4.1 (EN_UVLO); also elsewhere on the board
GND: C1.2, C3.2, C5.2, C6.2, C9.2, C10.2, C11.2, C12.2, C13.2, C14.2, C16.2, C17.2, C18.2, J2.A12 (GND), J2.B12 (GND), J2.SH (SHIELD), Q2.2 (S), Q3.2 (S), R3.2, R4.2, R28.2, R30.2, R31.2, R32.2, R39.2, U4.8 (GND), U8.3 (GND), U8.5 (GND), U8.7 (PAD), U11.3 (GND), U11.8 (GND), U14.4 (OV2), U14.5 (OV1), U14.6 (PR1), U14.12 (GND); also elsewhere on the board
HIL_FLT_N: R34.2, U4.4 (FLT); also elsewhere on the board
HIL_VBUS_EN: R27.1; also elsewhere on the board
unnamed: Q3.3 (D), R36.2
unnamed: C14.1, U4.7 (DVDT)
U4_ILM: R31.1, U4.9 (ILM); also elsewhere on the board
U14_ST: R33.1, U14.9 (ST); also elsewhere on the board
VBUS_HIL: C11.1, C12.1, C13.1, R36.1, R38.1, U4.6 (OUT); also elsewhere on the board
VBUS_HIL_SNS: R40.2; also elsewhere on the board
VBUS_PWR: C3.1, J2.A9 (VBUS), J2.B9 (VBUS), U14.2 (IN2), U14.3 (CP2); also elsewhere on the board
VBUS_UP: C1.1, U14.7 (IN1); also elsewhere on the board
VSYS: C5.1, C9.1, C10.1, C16.1, R29.1, U4.5 (IN), U8.4 (EN), U8.6 (IN), U14.1 (OUT), U14.8 (OUT); also elsewhere on the board

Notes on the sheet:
Generate 3.3v
USB Charger input.
Overvoltage
ESD for J2
VSYS is the result
VBUS_HIL discharge on disconect
Select power from J1 or J2
eFuse. Control power to DUT (VBUS_HIL)

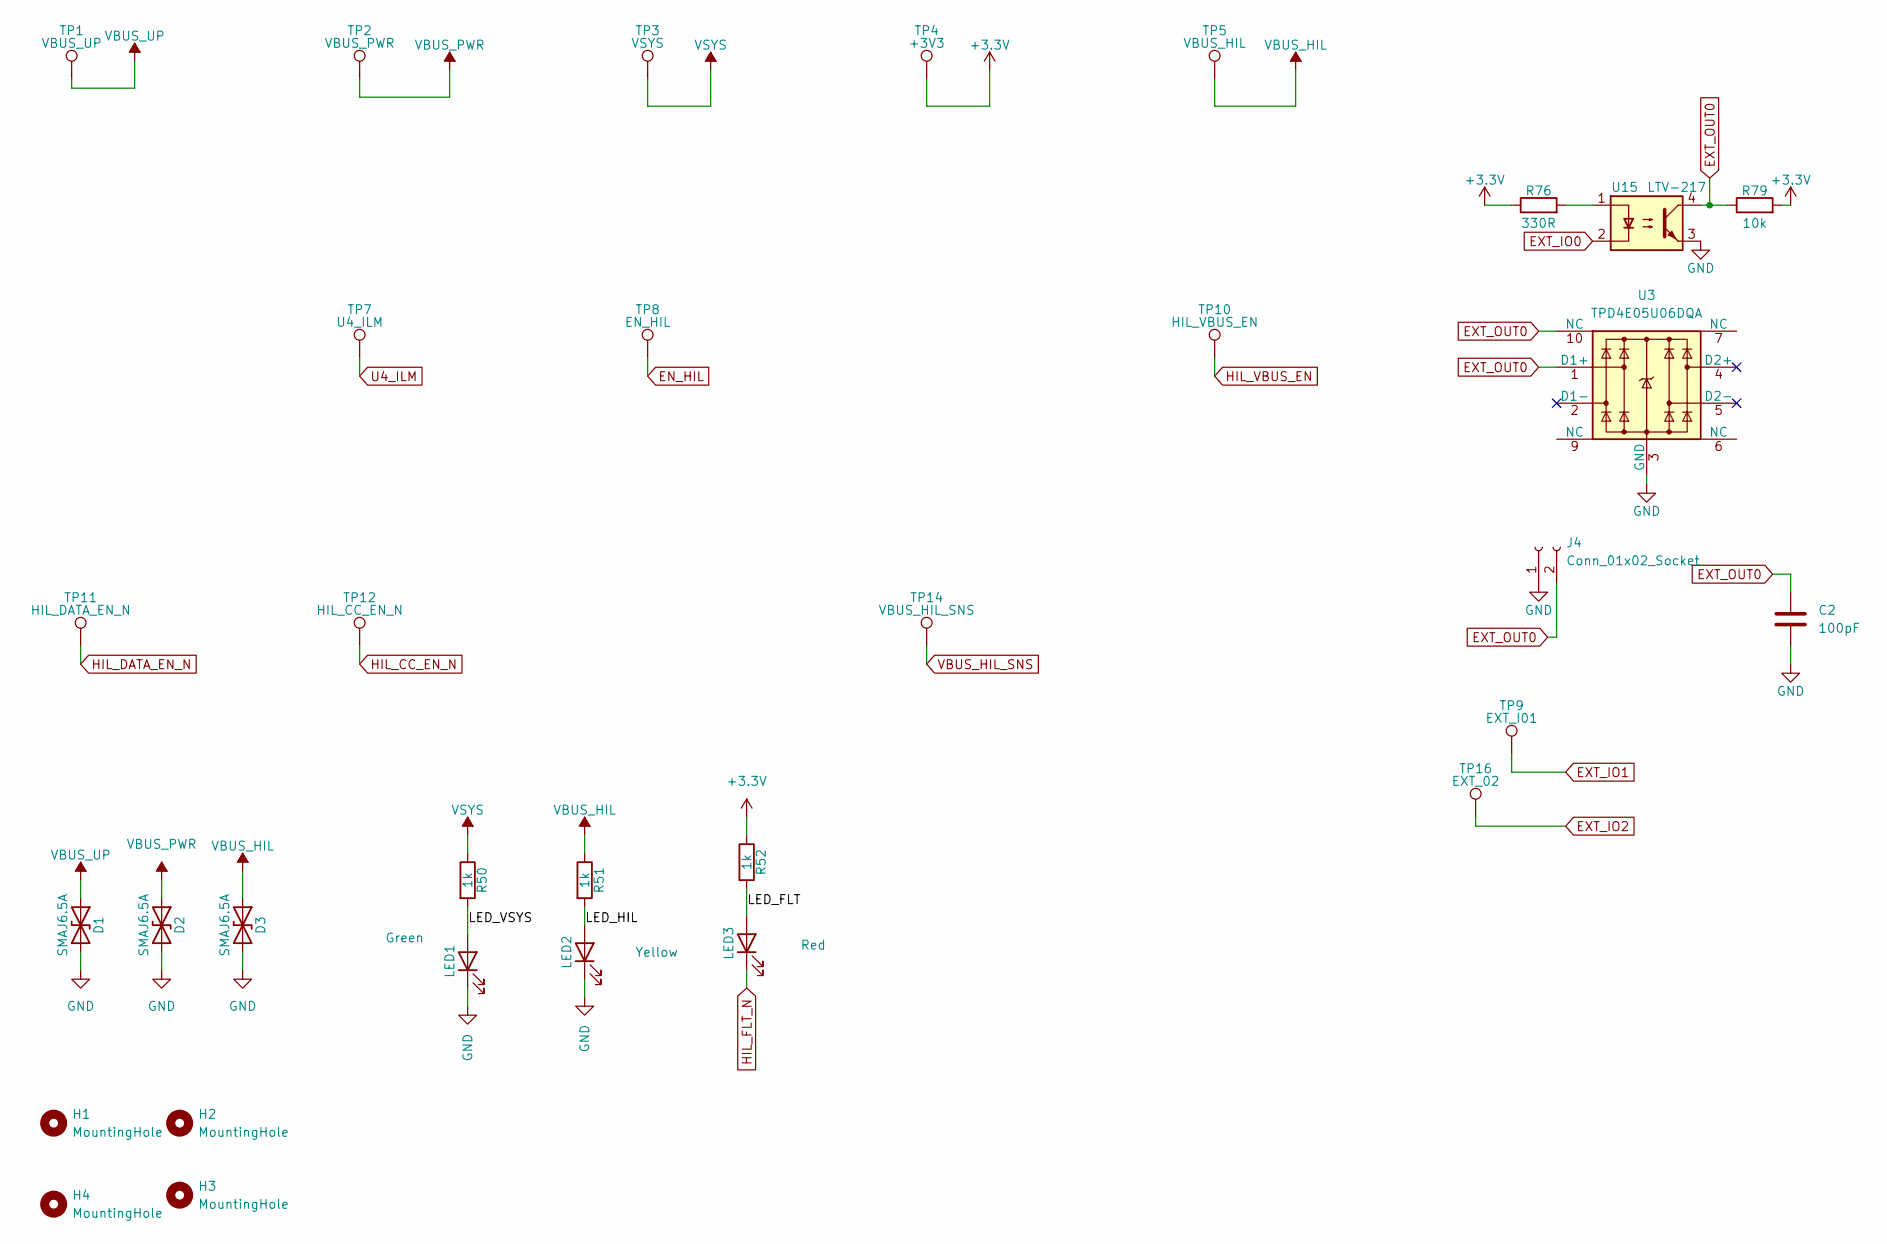
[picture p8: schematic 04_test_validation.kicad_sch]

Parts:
C2: 100pF; C_0402_1005Metric; LCSC C1546
D1, D2, D3: SMAJ6.5A; D_SMA; LCSC C123817
H1, H2, H3, H4: MountingHole; MountingHole_2.2mm_M2
J4: Conn_01x02_Socket; PinHeader_1x02_P2.54mm_Vertical
LED1: Green; LED_0805_2012Metric; LCSC C2297
LED2: Yellow; LED_0805_2012Metric; LCSC C2296
LED3: Red; LED_0603_1608Metric; LCSC C2286
R50, R51, R52: 1k; R_0402_1005Metric; LCSC C11702
R76: 330R; R_0402_1005Metric; LCSC C25104
R79: 10k; R_0402_1005Metric; LCSC C25744
TP1: VBUS_UP; TestPoint_Pad_D1.5mm
TP2: VBUS_PWR; TestPoint_Pad_D1.5mm
TP3: VSYS; TestPoint_Pad_D1.5mm
TP4: +3V3; TestPoint_Pad_D1.5mm
TP5: VBUS_HIL; TestPoint_Pad_D2.0mm
TP7: U4_ILM; TestPoint_Pad_D1.5mm
TP8: EN_HIL; TestPoint_Pad_D1.5mm
TP9: EXT_I01; TestPoint_Pad_D1.5mm
TP10: HIL_VBUS_EN; TestPoint_Pad_D1.5mm
TP11: HIL_DATA_EN_N; TestPoint_Pad_D1.5mm
TP12: HIL_CC_EN_N; TestPoint_Pad_D1.5mm
TP14: VBUS_HIL_SNS; TestPoint_Pad_D1.5mm
TP16: EXT_02; TestPoint_Pad_D1.5mm
U3: TPD4E05U06DQA; USON-10_2.5x1.0mm_P0.5mm; LCSC C138714
U15: LTV-217; SOP-4_4.4x2.6mm_P1.27mm; LCSC C115450

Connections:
+3.3V: R52.1, R76.1, R79.2, TP4.1 (1_1); also elsewhere on the board
/Test and Validation/LED_FLT: LED3.2 (A), R52.2
/Test and Validation/LED_HIL: LED2.2 (A), R51.2
/Test and Validation/LED_VSYS: LED1.2 (A), R50.2
EN_HIL: TP8.1 (1_1); also elsewhere on the board
EXT_IO0: U15.2; also elsewhere on the board
EXT_IO1: TP9.1 (1_1); also elsewhere on the board
EXT_IO2: TP16.1 (1_1); also elsewhere on the board
EXT_OUT0: C2.1, J4.2, R79.1, U3.1 (D1+), U3.10 (NC), U15.4
GND: C2.2, D1.2 (A2), D2.2 (A2), D3.2 (A2), J4.1, LED1.1 (K), LED2.1 (K), U3.3 (GND), U3.8 (GND), U15.3; also elsewhere on the board
HIL_CC_EN_N: TP12.1 (1_1); also elsewhere on the board
HIL_DATA_EN_N: TP11.1 (1_1); also elsewhere on the board
HIL_FLT_N: LED3.1 (K); also elsewhere on the board
HIL_VBUS_EN: TP10.1 (1_1); also elsewhere on the board
unnamed: R76.2, U15.1
U4_ILM: TP7.1 (1_1); also elsewhere on the board
VBUS_HIL: D3.1 (A1), R51.1, TP5.1 (1_1); also elsewhere on the board
VBUS_HIL_SNS: TP14.1 (1_1); also elsewhere on the board
VBUS_PWR: D2.1 (A1), TP2.1 (1_1); also elsewhere on the board
VBUS_UP: D1.1 (A1), TP1.1 (1_1); also elsewhere on the board
VSYS: R50.1, TP3.1 (1_1); also elsewhere on the board

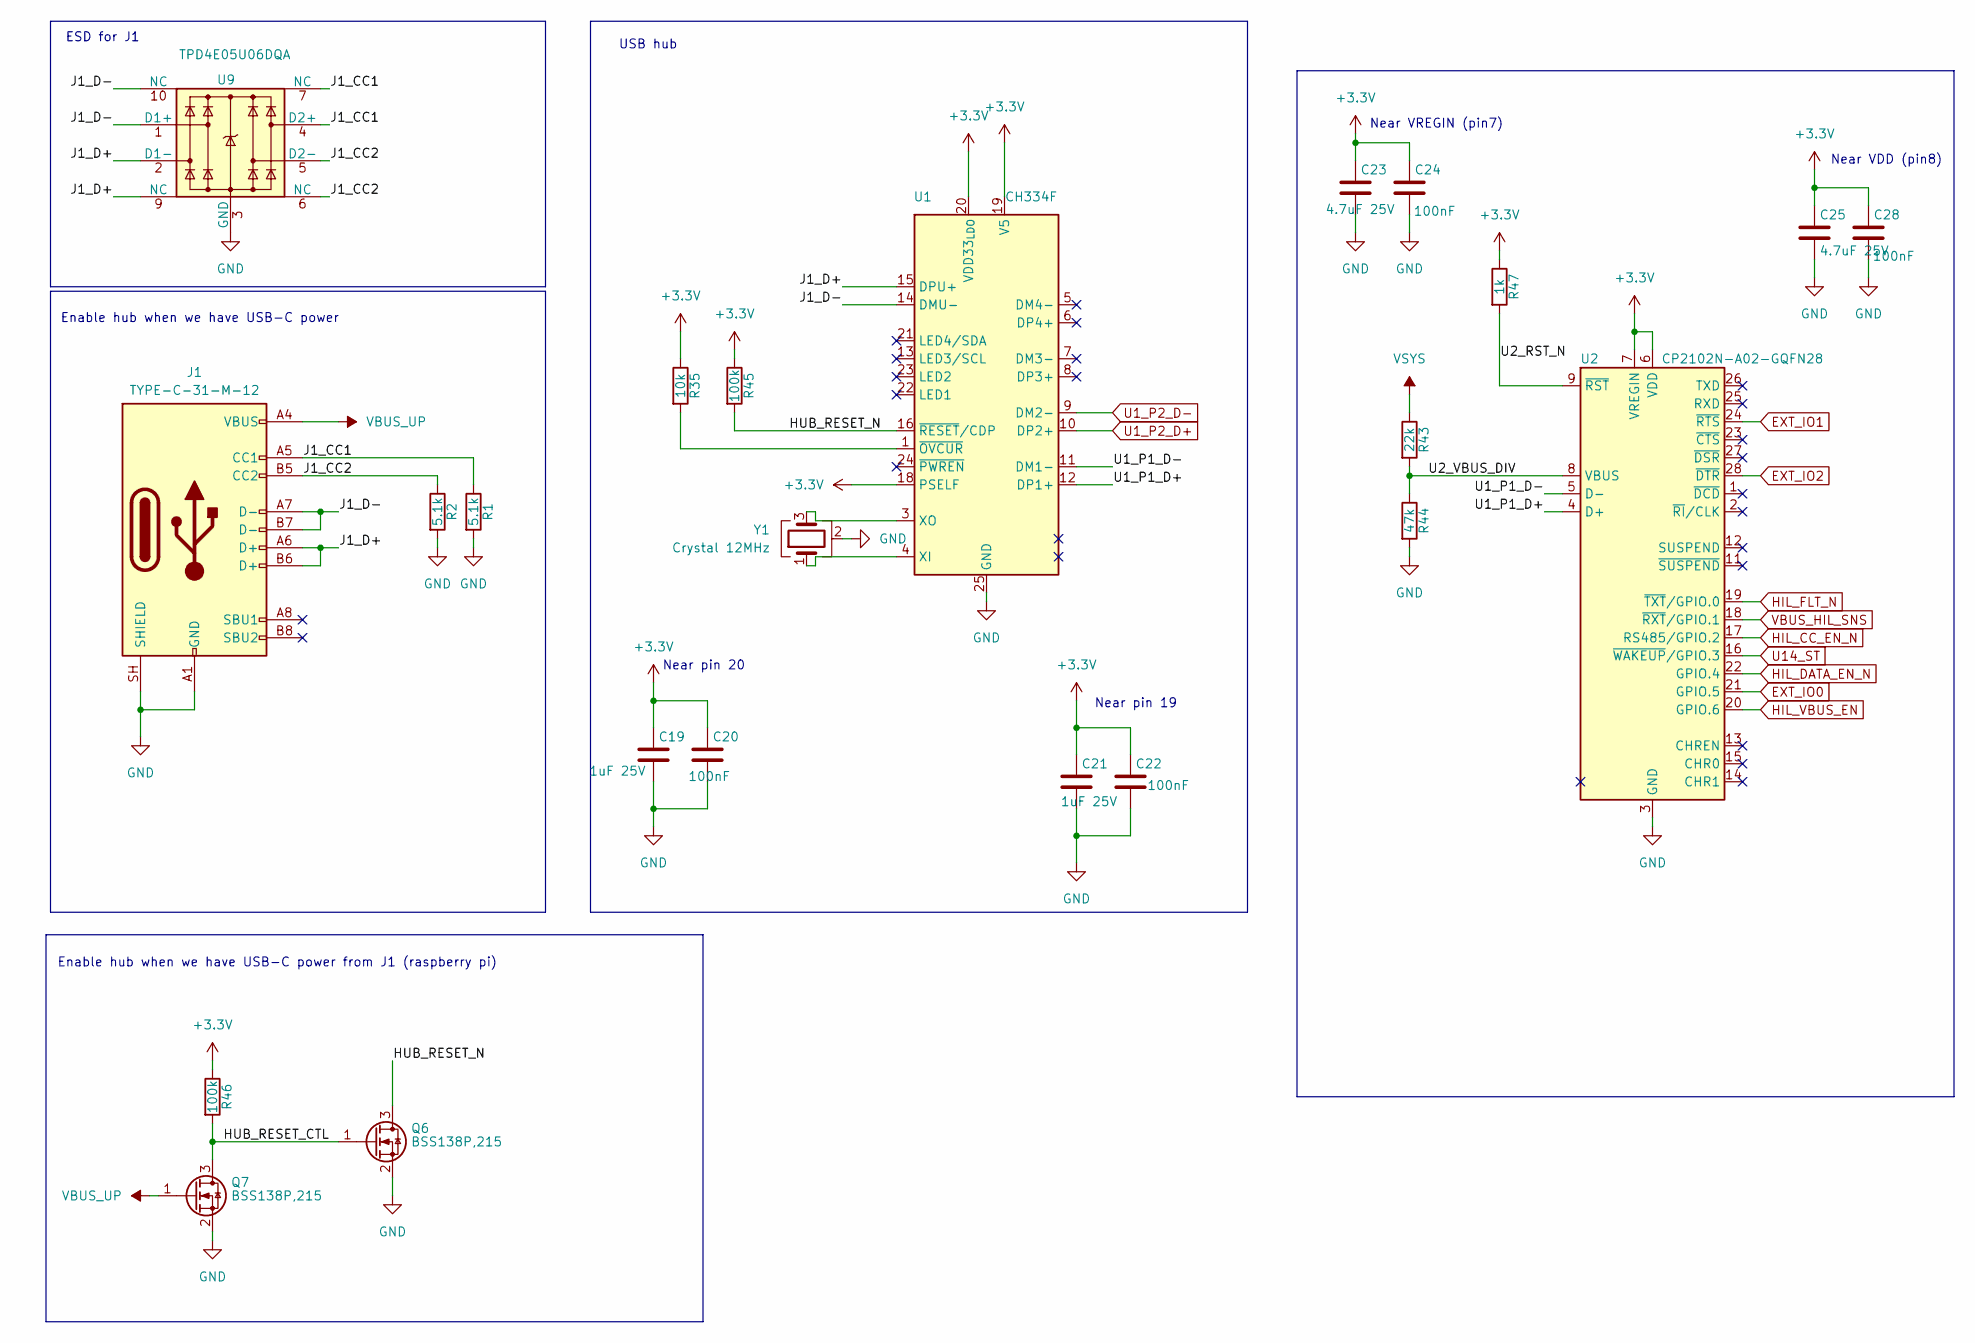
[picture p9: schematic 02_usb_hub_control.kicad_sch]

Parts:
C19, C21: 1uF 25V; C_0402_1005Metric; LCSC C52923
C20, C22, C24, C28: 100nF; C_0402_1005Metric; LCSC C1525
C23, C25: 4.7uF 25V; C_0805_2012Metric; LCSC C1779
J1: TYPE-C-31-M-12; USB_C_Receptacle_HRO_TYPE-C-31-M-12; LCSC C165948
Q6, Q7: BSS138P,215; SOT-23; LCSC C75547
R1, R2: 5.1k; R_0402_1005Metric; LCSC C25905
R35: 10k; R_0402_1005Metric; LCSC C25744
R43: 22k; R_0402_1005Metric; LCSC C25768
R44: 47k; R_0402_1005Metric; LCSC C25792
R45, R46: 100k; R_0402_1005Metric; LCSC C25741
R47: 1k; R_0402_1005Metric; LCSC C11702
U1: CH334F; QFN-24-1EP_4x4mm_P0.5mm_EP2.7x2.7mm; LCSC C5187527
U2: CP2102N-A02-GQFN28; QFN-28-1EP_5x5mm_P0.5mm_EP3.25x3.25mm; LCSC C964632
U9: TPD4E05U06DQA; USON-10_2.5x1.0mm_P0.5mm; LCSC C138714
Y1: Crystal 12MHz; Crystal_SMD_3225-4Pin_3.2x2.5mm; LCSC C9002

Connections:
+3.3V: C19.1, C20.1, C21.1, C22.1, C23.1, C24.1, C25.1, C28.1, R35.1, R45.1, R46.1, R47.1, U1.18 (PSELF), U1.19 (V5), U1.20 (VDD33_{LDO}), U2.6 (VDD), U2.7 (VREGIN); also elsewhere on the board
/USB Hub and Control/HUB_RESET_CTL: Q6.1 (G), Q7.3 (D), R46.2
/USB Hub and Control/HUB_RESET_N: Q6.3 (D), R45.2, U1.16 (~RESET/CDP)
/USB Hub and Control/J1_CC1: J1.A5 (CC1), R1.1, U9.4 (D2+), U9.7 (NC)
/USB Hub and Control/J1_CC2: J1.B5 (CC2), R2.1, U9.5 (D2-), U9.6 (NC)
/USB Hub and Control/J1_D+: J1.A6 (D+), J1.B6 (D+), U1.15 (DPU+), U9.2 (D1-), U9.9 (NC)
/USB Hub and Control/J1_D-: J1.A7 (D-), J1.B7 (D-), U1.14 (DMU-), U9.1 (D1+), U9.10 (NC)
/USB Hub and Control/U1_P1_D+: U1.12 (DP1+), U2.4 (D+)
/USB Hub and Control/U1_P1_D-: U1.11 (DM1-), U2.5 (D-)
/USB Hub and Control/U2_RST_N: R47.2, U2.9 (~RST)
/USB Hub and Control/U2_VBUS_DIV: R43.2, R44.1, U2.8 (VBUS)
EXT_IO0: U2.21 (GPIO.5); also elsewhere on the board
EXT_IO1: U2.24 (~RTS); also elsewhere on the board
EXT_IO2: U2.28 (~DTR); also elsewhere on the board
GND: C19.2, C20.2, C21.2, C22.2, C23.2, C24.2, C25.2, C28.2, J1.A1 (GND), J1.A12 (GND), J1.B1 (GND), J1.B12 (GND), J1.SH (SHIELD), Q6.2 (S), Q7.2 (S), R1.2, R2.2, R44.2, U1.25 (GND), U2.3 (GND), U2.29 (GND), U9.3 (GND), U9.8 (GND), Y1.2 (G), Y1.4 (G); also elsewhere on the board
HIL_CC_EN_N: U2.17 (RS485/GPIO.2); also elsewhere on the board
HIL_DATA_EN_N: U2.22 (GPIO.4); also elsewhere on the board
HIL_FLT_N: U2.19 (~TXT/GPIO.0); also elsewhere on the board
HIL_VBUS_EN: U2.20 (GPIO.6); also elsewhere on the board
unnamed: U1.4 (XI), Y1.1
unnamed: U1.3 (XO), Y1.3
unnamed: R35.2, U1.1 (~OVCUR)
U1_P2_D+: U1.10 (DP2+); also elsewhere on the board
U1_P2_D-: U1.9 (DM2-); also elsewhere on the board
U14_ST: U2.16 (~WAKEUP/GPIO.3); also elsewhere on the board
VBUS_HIL_SNS: U2.18 (~RXT/GPIO.1); also elsewhere on the board
VBUS_UP: J1.A4 (VBUS), J1.A9 (VBUS), J1.B4 (VBUS), J1.B9 (VBUS), Q7.1 (G); also elsewhere on the board
VSYS: R43.1; also elsewhere on the board

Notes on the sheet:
Near VDD (pin8)
Enable hub when we have USB-C power
ESD for J1
Near VREGIN (pin7)
USB hub
Near pin 20
Enable hub when we have USB-C power from J1 (raspberry pi)
Near pin 19

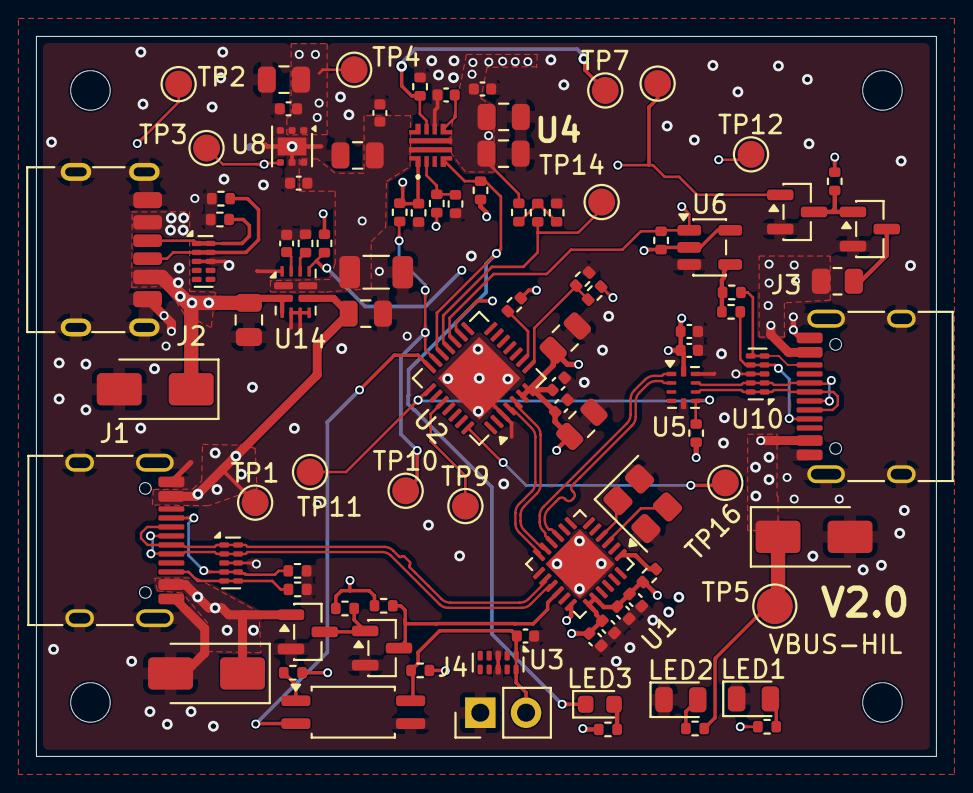
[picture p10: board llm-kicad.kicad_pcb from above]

Board: 4 copper layers, 50.0 x 40.0 mm, 100 parts (0 on the bottom side), 51 nets.

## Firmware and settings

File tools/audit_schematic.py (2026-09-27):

#!/usr/bin/env python3
"""Schematic audit for the USB-C HIL Control project (llm-kicad).

Run:  python3 tools/audit_schematic.py

Checks, highest value first:

  1. symbol pin numbers vs placed footprint pad numbers
     -> the M1 / H6 defect class (silent pin-to-pad mismatch).
        Nothing in KiCad checks this: ERC's `footprint_filter` compares only
        name filters, never pin numbers. Re-run after ANY symbol or footprint
        change.
  2. schematic `Footprint` field vs the footprint actually placed on the board
     -> detects a schematic/PCB that are out of sync.
  3. `Value` text vs the JLCPCB catalogue part for each LCSC code
     -> the H5 / M11 defect class (BOM part contradicting the schematic text).
        Compares both the voltage rating and the capacitance.
  4. `Datasheet` property coverage, and flags values that cannot resolve.

Exit code is non-zero if check 1 or 2 finds anything, so it can gate a commit.
"""
import os
import re
import sqlite3
import sys
from collections import Counter

PRJ = os.path.join(os.path.dirname(os.path.dirname(os.path.abspath(__file__))), "llm-kicad")
SHEETS = ["01_power_cc", "02_usb_hub_control", "03_dut_interface", "04_test_validation"]
DB = os.path.expanduser("~/.konnect/jlcpcb.db")


# --------------------------------------------------------------------------- #
# parsing
# --------------------------------------------------------------------------- #
def sexp_block(txt, start):
    """Return the balanced s-expression beginning at txt[start] (which is '(')."""
    depth, instr, i = 0, False, start
    while i < len(txt):
        ch = txt[i]
        if ch == '"' and txt[i - 1] != "\\":
            instr = not instr
        elif not instr:
            if ch == "(":
                depth += 1
            elif ch == ")":
                depth -= 1
                if depth == 0:
                    return txt[start:i + 1]
        i += 1
    raise ValueError("unbalanced s-expression")


def load_schematic():
    """ref -> {sheet, lib_id, value, footprint, lcsc, datasheet, pins:set}"""
    comps = {}
    for sheet in SHEETS:
        path = os.path.join(PRJ, sheet + ".kicad_sch")
        if not os.path.exists(path):
            continue
        txt = open(path, encoding="utf-8").read()
        for m in re.finditer(r"\n\t\(symbol\n", txt):
            body = sexp_block(txt, txt.index("(", m.start()))
            props = dict(re.findall(r'\(property\s+"([^"]+)"\s+"((?:[^"\\]|\\.)*)"', body))
            ref = props.get("Reference", "").split("_")[0]
            if not ref or ref.startswith("#"):
                continue
            lib = re.search(r'\(lib_id\s+"([^"]+)"', body)
            comps[ref] = dict(
                sheet=sheet,
                lib_id=lib.group(1) if lib else "",
                value=props.get("Value", ""),
                footprint=props.get("Footprint", ""),
                lcsc=props.get("LCSC", ""),
                datasheet=props.get("Datasheet", ""),
                pins=set(re.findall(r'\(pin\s+"([^"]+)"', body)),
            )
    return comps


def load_board():
    """ref -> (footprint name, set of pad numbers) from the placed board."""
    path = os.path.join(PRJ, "llm-kicad.kicad_pcb")
    txt = open(path, encoding="utf-8").read()
    out = {}
    for m in re.finditer(r'\n\t\(footprint\s+"([^"]+)"', txt):
        body = sexp_block(txt, txt.index("(", m.start()))
        ref = re.search(r'\(property\s+"Reference"\s+"([^"]+)"', body)
        if not ref:
            continue
        out[ref.group(1)] = (m.group(1), set(re.findall(r'\(pad\s+"([^"]+)"', body)))
    return out


def load_netlist(path="/tmp/net.net"):
    """ref -> {pin: pinfunction} from a kicadsexpr netlist, if one is available."""
    if not os.path.exists(path):
        return {}
    txt = open(path, encoding="utf-8").read()
    out = {}
    for ref, pin, fn in re.findall(
            r'\(ref "([^"]+)"\)\s*\n\s*\(pin "([^"]+)"\)\s*\n\s*\(pinfunction "([^"]*)"\)', txt):
        out.setdefault(ref, {})[pin] = fn
    return out


# --------------------------------------------------------------------------- #
# checks
# --------------------------------------------------------------------------- #
def check_pin_pad(comps, board):
    print("=" * 78)
    print("1. SYMBOL PIN NUMBERS vs PLACED FOOTPRINT PAD NUMBERS   (M1 / H6 class)")
    print("=" * 78)
    bad = []
    for ref in sorted(board):
        if ref not in comps:
            print(f"  !! on the board but not in the schematic: {ref}")
            continue
        pins, pads = comps[ref]["pins"], board[ref][1]
        if not pins or not pads or pins == pads:
            continue
        bad.append(ref)
        print(f"  {ref}  {board[ref][0]}")
        if pins - pads:
            print(f"        PINS WITH NO PAD: {sorted(pins - pads, key=sortkey)}")
        if pads - pins:
            print(f"        PADS WITH NO PIN: {sorted(pads - pins, key=sortkey)}")
    print(f"  -> {len(bad)} mismatching component(s) of {len(board)} placed\n")
    return bad


def check_sync(comps, board):
    print("=" * 78)
    print("2. SCHEMATIC 'Footprint' FIELD vs PLACED FOOTPRINT")
    print("=" * 78)
    bad = []
    for ref in sorted(board):
        if ref in comps and (comps[ref]["footprint"] or "") != board[ref][0]:
            bad.append(ref)
            print(f"  {ref}  schematic: {comps[ref]['footprint']}")
            print(f"       pcb      : {board[ref][0]}")
    print(f"  -> {len(bad)} mismatch(es) of {len(board)} placed\n")
    return bad


def sortkey(s):
    return (len(s), s)


def nums(text, unit):
    """All <number><unit> occurrences in a description, e.g. ('100','uF')."""
    return [float(m.group(1)) for m in
            re.finditer(r'(\d+(?:\.\d+)?)\s*' + unit + r'\b', text, re.I)]


def check_values(comps):
    print("=" * 78)
    print("3. 'Value' TEXT vs JLCPCB CATALOGUE PART                     (H5 / M11 class)")
    print("=" * 78)
    if not os.path.exists(DB):
        print(f"  catalogue not found at {DB} -- skipped\n")
        return []
    conn = sqlite3.connect(f"file:{DB}?mode=ro", uri=True)
    seen, flagged = set(), []
    for ref in sorted(comps, key=lambda r: (r[0], sortkey(r))):
        lcsc = (comps[ref]["lcsc"] or "").strip()
        if not lcsc or lcsc in seen:
            continue
        seen.add(lcsc)
        row = conn.execute(
            "SELECT MFR_Part, Package, Library_Type, Description, Stock, Price"
            " FROM components WHERE LCSC=?", (lcsc,)).fetchone()
        if not row:
            print(f"  {ref:5s} {lcsc:9s} *** NOT IN CATALOGUE ***")
            continue
        mfr, pkg, lib, desc = row[0], row[1], row[2], row[3] or ""
        value = comps[ref]["value"] or ""
        volts = nums(value, "V")
        cap_v = nums(desc, "V")
        cap_f = nums(desc, "uF") + [x / 1000 for x in nums(desc, "nF")]
        val_f = nums(value, "uF") + [x / 1000 for x in nums(value, "nF")]
        notes = []
        # only compare a voltage when the value text declares one and the part is a cap/diode
        if volts and cap_v and abs(volts[0] - min(cap_v)) > 0.5:
            notes.append(f"VOLTAGE: value {volts[0]:g} V vs part {min(cap_v):g} V")
        if val_f and cap_f:
            part_f = cap_f[0]
            if part_f and abs(val_f[0] - part_f) / part_f > 0.25:
                notes.append(f"CAPACITANCE: value {val_f[0]:g} uF vs part {part_f:g} uF")
        if notes:
            flagged.append(ref)
            print(f"  {ref:5s} {lcsc:9s} {value[:15]:15s} {pkg[:16]:16s} {lib:9s} "
                  f"{mfr[:20]:20s} {desc[:34]}")
            for n in notes:
                print(f"        >>> {n}")
    print(f"  -> {len(flagged)} flagged component(s) of {len(seen)} unique LCSC codes\n")
    return flagged


def check_datasheets(comps):
    print("=" * 78)
    print("4. 'Datasheet' PROPERTY COVERAGE")
    print("=" * 78)
    have = [r for r in comps if comps[r]["datasheet"]]
    print(f"  {len(have)} of {len(comps)} components carry a Datasheet value")
    for ref in sorted(have):
        v = comps[ref]["datasheet"]
        warn = ""
        if not re.match(r"^https?://", v):
            warn = "   <<< does not resolve (no scheme / relative path)"
        elif not os.path.exists(v) and "://" not in v:
            warn = "   <<< local path missing"
        print(f"    {ref:5s} {v[:86]}{warn}")
    print()


def main():
    comps, board = load_schematic(), load_board()
    print(f"project : {PRJ}")
    print(f"parsed  : {len(comps)} schematic components, {len(board)} placed footprints\n")
    bad = check_pin_pad(comps, board) + check_sync(comps, board)
    check_values(comps)
    check_datasheets(comps)
    nl = load_netlist()
    if nl:
        print("netlist pin functions available at /tmp/net.net "
              f"({len(nl)} components) -- exported with:")
        print("  kicad-cli sch export netlist --format kicadsexpr -o /tmp/net.net "
              "llm-kicad.kicad_sch\n")
    print("resolve differences with:")
    print("  kicad-cli sch erc --severity-all --format report -o /tmp/erc.rpt llm-kicad.kicad_sch")
    return 1 if bad else 0


if __name__ == "__main__":
    sys.exit(main())

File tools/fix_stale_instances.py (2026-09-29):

#!/usr/bin/env python3
"""Remove the stray per-project instance records that block Konnect's edit tools.

THE PROBLEM (review finding M10)
--------------------------------
KiCad records, inside every placed symbol, one ``(project "<name>" (path ...))``
entry per project that uses that sheet. A sub-sheet can legitimately be shared by
several projects, so those entries are a feature, not junk -- which is why KiCad
has no "clean up" command for them.

When a ``.kicad_sch`` is opened *standalone* instead of through its project, KiCad
treats the file as its own project, named after the file, and writes an extra
entry:

    (instances
        (project "llm-kicad"          <-- correct: root uuid / sheet uuid
            (path "/359235dd-.../63913550-..." (reference "R27") (unit 1)))
        (project "01_power_cc"        <-- stray: the sheet file as its own root
            (path "/5ebe429a-..."            (reference "R27") (unit 1)))
    )

The stray entry makes Konnect's field resolver see a symbol belonging to two
projects and refuse with ``ambiguous_target``, which blocks scripted edits on
U1, U2, U5, U6, U9, U10, J1 and J3.

THE FIX
-------
Delete exactly the ``(project "<sheetfile>" ...)`` entries. That is safe here
because every affected symbol also carries its correct ``llm-kicad`` entry, with
the same reference and unit -- so no annotation is lost. This script proves that
before touching anything: if any symbol would be left with no valid record, it
refuses and changes nothing.

SAFETY
------
* Dry run by default -- nothing is written unless you pass --apply.
* Refuses if any symbol would lose its only instance record.
* Writes a timestamped ``.bak`` next to each sheet before modifying it.
* Re-reads the files afterwards and re-verifies reference designators and the
  absence of stray records.

USAGE
-----
    # ALWAYS: close KiCad first. A save from a running editor overwrites this.
    python3 tools/fix_stale_instances.py            # dry run, shows the plan
    python3 tools/fix_stale_instances.py --apply    # perform it
"""
import argparse
import os
import re
import shutil
import sys
import time

ROOT = os.path.dirname(os.path.dirname(os.path.abspath(__file__)))
PRJ = os.path.join(ROOT, "llm-kicad")
PROJECT = "llm-kicad"
SHEETS = ["01_power_cc", "02_usb_hub_control", "03_dut_interface", "04_test_validation"]


def match_block(txt, start):
    """Index just past the ')' matching the '(' at txt[start]."""
    depth, instr, i = 0, False, start
    while i < len(txt):
        ch = txt[i]
        if ch == '"' and txt[i - 1] != "\\":
            instr = not instr
        elif not instr:
            if ch == "(":
                depth += 1
            elif ch == ")":
                depth -= 1
                if depth == 0:
                    return i + 1
        i += 1
    raise ValueError("unbalanced s-expression")


def plan_sheet(path, sheet):
    """Return (edits, refs_kept, problems).

    edits: list of (start, end) character spans to delete, extended backwards
    over the preceding newline and indentation so no blank line is left behind.
    """
    txt = open(path, encoding="utf-8").read()
    edits, refs, problems = [], [], []

    for m in re.finditer(r"\n\t\(symbol\n", txt):
        sym_start = txt.index("(", m.start())
        sym_end = match_block(txt, sym_start)
        block = txt[sym_start:sym_end]

        ref = re.search(r'\(property\s+"Reference"\s+"([^"]+)"', block)
        ref = ref.group(1) if ref else "?"

        inst = block.find("(instances")
        if inst < 0:
            continue
        inst_end = match_block(block, inst)

        good, targets = 0, []
        for pm in re.finditer(r'\(project\s+"([^"]+)"', block[inst:inst_end]):
            name = pm.group(1)
            if name == PROJECT:
                good += 1
            elif name == sheet:
                s = inst + pm.start()
                e = match_block(block, s)
                targets.append((s, e))

        if not targets:
            continue
        if good == 0:
            problems.append(f"{sheet}:{ref} has ONLY a stray record - refusing")
            continue

        refs.append(ref)
        for s, e in targets:
            # extend back over the newline and indentation preceding the record
            a = sym_start + s
            while a > sym_start and txt[a - 1] in " \t":
                a -= 1
            if a > sym_start and txt[a - 1] == "\n":
                a -= 1
            edits.append((a, sym_start + e))

    edits.sort()
    return edits, refs, problems


def main():
    ap = argparse.ArgumentParser(description=__doc__,
                                 formatter_class=argparse.RawDescriptionHelpFormatter)
    ap.add_argument("--apply", action="store_true",
                    help="actually write the files (default is a dry run)")
    args = ap.parse_args()

    if not os.path.isdir(PRJ):
        print(f"project folder not found: {PRJ}")
        return 2

    total, all_refs, all_problems, per_file = 0, [], [], {}
    for sheet in SHEETS:
        path = os.path.join(PRJ, sheet + ".kicad_sch")
        if not os.path.exists(path):
            continue
        edits, refs, problems = plan_sheet(path, sheet)
        per_file[sheet] = (path, edits, refs)
        total += len(edits)
        all_refs += refs
        all_problems += problems

    print(f"project            : {PRJ}")
    print(f"stray records found: {total}")
    for sheet, (path, edits, refs) in per_file.items():
        if edits:
            print(f"  {sheet:22s} {len(edits):2d} records on {len(refs):2d} symbols")
    print()

    if all_problems:
        print("REFUSING - these symbols would lose their only instance record:")
        for p in all_problems:
            print("   " + p)
        print("\nNothing was written. Annotate those symbols in KiCad first.")
        return 1

    if not total:
        print("Nothing to do - no stray instance records present.")
        return 0

    if not args.apply:
        print("Dry run: no files changed. Re-run with --apply to perform the edit.")
        print("\nBefore applying:\n"
              "  1. Close KiCad (a save from a running editor would overwrite this).\n"
              "  2. Make sure the project is committed, or rely on the .bak files.")
        return 0

    stamp = time.strftime("%Y%m%d-%H%M%S")
    for sheet, (path, edits, refs) in per_file.items():
        if not edits:
            continue
        shutil.copy2(path, f"{path}.{stamp}.bak")
        txt = open(path, encoding="utf-8").read()
        for a, b in sorted(edits, reverse=True):
            txt = txt[:a] + txt[b:]
        open(path, "w", encoding="utf-8").write(txt)
        print(f"  rewrote {sheet}.kicad_sch ({len(edits)} records removed), "
              f"backup .{stamp}.bak")
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

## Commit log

2026-09-27 Added first version
    [01_power_cc.kicad_sch, 02_usb_hub_control.kicad_sch, 03_dut_interface.kicad_sch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]
2026-09-27 More progress
    [01_power_cc.kicad_sch, 02_usb_hub_control.kicad_sch, 03_dut_interface.kicad_sch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]
2026-09-28 Update before fixing M10
    [01_power_cc.kicad_sch, llm-kicad.kicad_pcb]
2026-09-28 After fixing M10
    [01_power_cc.kicad_sch, 02_usb_hub_control.kicad_sch, 03_dut_interface.kicad_sch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]
2026-09-29 Fixed incorrect footprint and added external GPIO
    [01_power_cc.kicad_sch, 02_usb_hub_control.kicad_sch, 03_dut_interface.kicad_sch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]
2026-09-30 Don't track archive
2026-09-30 Ready for first production
    [04_test_validation.kicad_sch, llm-kicad.kicad_pcb]
2026-10-01 Production 2.0
    [usb-c-disconnect-2.0_bom.csv, usb-c-disconnect-2.0_designators.csv, usb-c-disconnect-2.0_positions.csv]
2026-10-01 Fixed namning of some components
    Remove footprint name
    [01_power_cc.kicad_sch, 04_test_validation.kicad_sch, llm-kicad.kicad_pcb]
2026-10-17 Add Linux control script with multi-board selection
    Add code/usb-ctr-linux.py (gpiochip-based) with support for several
    boards on one host: list, port/index/serial selection, all-on/all-off/
    all-toggle, --all, and toggle. Refuses to guess when more than one board
    is attached and no selector is given.
2026-10-17 Add Mac control script with multi-board selection
    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
